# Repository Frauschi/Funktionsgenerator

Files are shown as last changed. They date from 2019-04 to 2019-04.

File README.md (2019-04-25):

# Funktionsgenerator

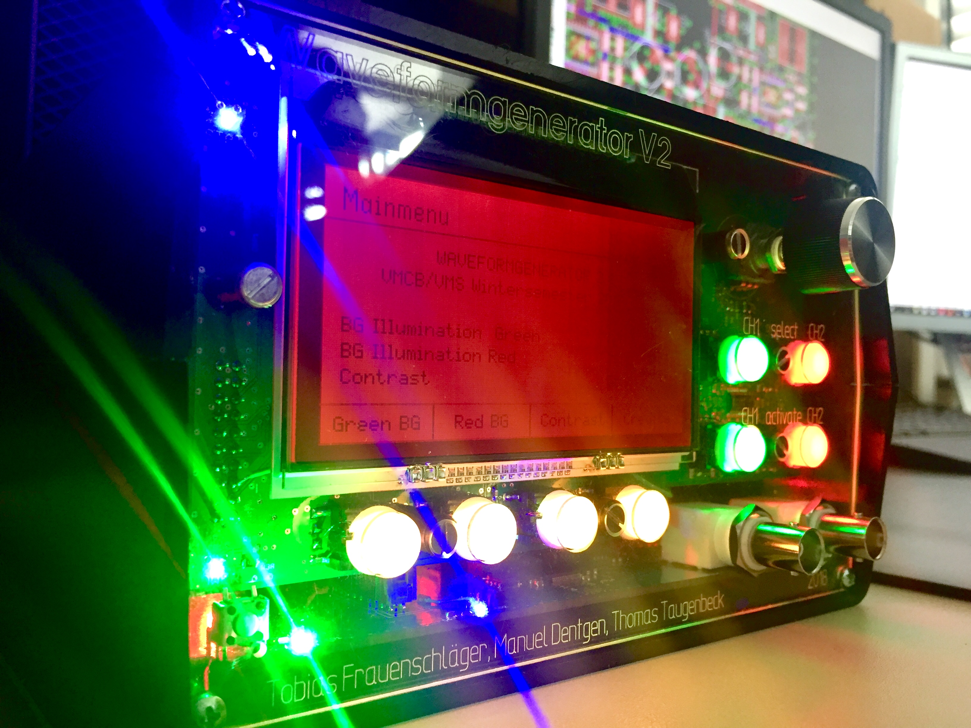
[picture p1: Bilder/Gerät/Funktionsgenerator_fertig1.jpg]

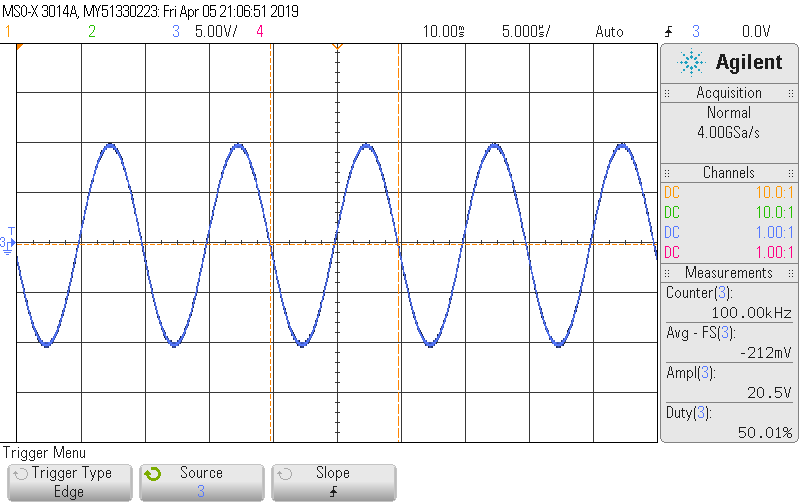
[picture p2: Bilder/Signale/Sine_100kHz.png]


Dieses Repository beinhaltet alle relevaten Dateien für den Bau eines Funktionsgenerators. Dieser ist
im Rahmen einer Projektarbeit and der *Ostbayerischen Technischen Hochschule Regensburg* enstanden.

### Specs des Funktionsgenerators

- Zwei unabhängige Ausgangskanäle
- Signalformen: Sinus, Recheck (einstellbarer Duty-Cycle), Dreieck, Sägezahn (ansteigend und abfallend)
- Frequenz: 1Hz – 10MHz
- Ausgangsspannung: -10V – +10V 
- Signal-Offset: -5V – +5V
- Signal-Phase -180° – +180°

### Entwickler

- Manuel Dentgen
- Tobias Frauenschläger
- Thomas Taugenbeck

### Verzeichnisstruktur

- `Bilder` 
	
	Dieses Verzeichnis beinhaltet sowohl Bilder vom Gerät selbst (3D Modell und tatsächliches Gerät) als 
	auch Bilder von den erzeugten Signalen.
	
- `Dokumentation` 

	Dieser Ordner enthält zum einen die Projektdokumentation und zum anderen eine Bedienungsanleitung für den 
	fertigen Funktionsgenerator.
	
- `Hardware` 

	Hier sind alle Dateien für die drei entwickelten Platinen abgelegt (Schaltplan und Layout).
	
- `Software` 
	
	In diesem Verzeichnis ist die Firmware für den Mikrocontroller zu finden, der das ganze Gerät steuert.

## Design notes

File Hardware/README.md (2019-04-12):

# Hardware Funktionsgenerator

In diesem Verzeichnis ist die selbstentwickelte Hardware für den Funktionsgenerator zu finden, 
aufgeteilt auf die drei Platinen `Frontpanel`, `Hauptplatine` und `Netzteilplatine`. Im jeweiligen Ordner 
sind die Schaltplan- und Layout-Dateien abgelegt, wobei diese mit dem Programm 
[Eagle](https://www.autodesk.com/products/eagle/overview) in Version 7.7 erstellt wurden. Die Schaltpläne
sind zudem als PDF verfügbar.

## Dokumentation

Die Dokumentation der Hardware ist in der Projektdokumentation im Verzeichnis `Dokumentation` zu finden.

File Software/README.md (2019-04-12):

# Software Funktionsgenerator

In diesem Verzeichnis ist die Firmware für den Funktionsgenerator zu finden. Es handelt sich 
um ein Projekt für die IDE [Eclipse](https://www.eclipse.org/ide/) mit dem Zusatzplugin 
[System Workbench for STM32](http://www.openstm32.org/System%2BWorkbench%2Bfor%2BSTM32). 

## Dokumentation

Für die Dokumentation des Codes bitte in der Projektdokumentation im Verzeichnis `Dokumentation` nachlesen.

## How to build

Nach dem Import in Eclipse sind zwei Konfigurationen vorhanden: `Debug` und `Release`. 

Ein `Debug` Build ermöglicht das Debuggen mittels GDB, wobei keinerlei Code-Optimierungen erfolgen.

Ein Build in der `Release` Konfiguration optimiert den Code mit `-Os`. Damit wird der Code um einiges
schneller und die Binary-Size deutlich kleiner, es kann jedoch nicht mehr gedebugged werden.

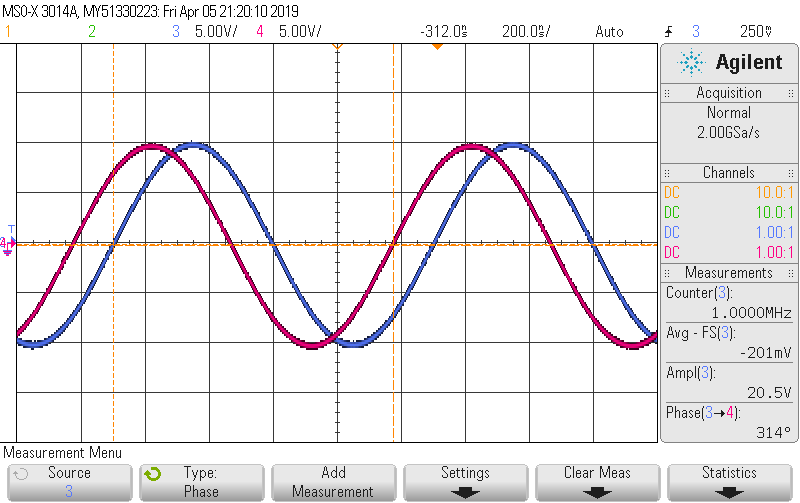
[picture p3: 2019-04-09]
Bilder/Signale/Sine_1MHz_-45deg.png

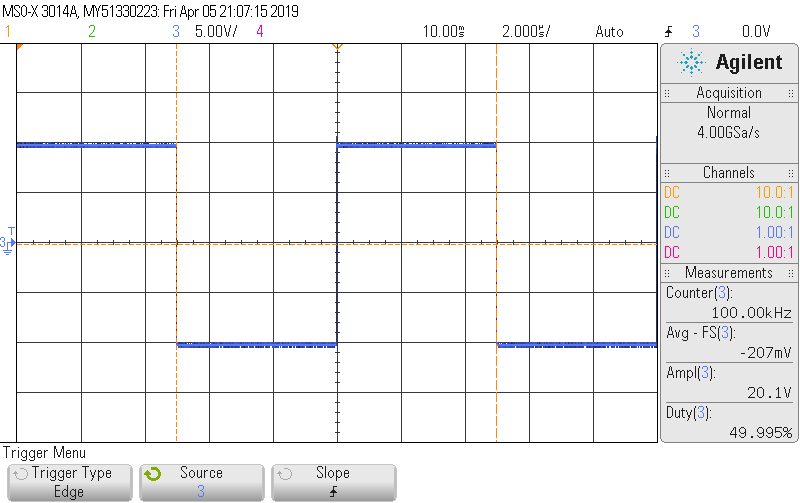
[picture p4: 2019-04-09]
Bilder/Signale/Rect_100kHz.png

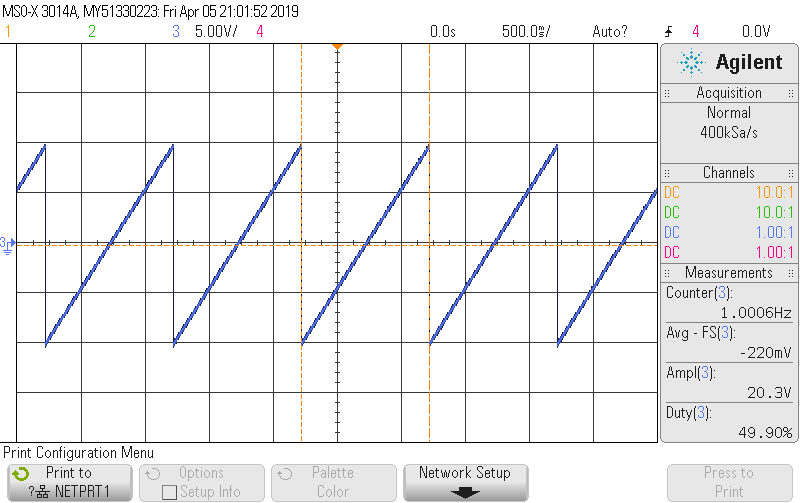
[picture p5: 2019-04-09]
Bilder/Signale/Saw_pos_1Hz.png

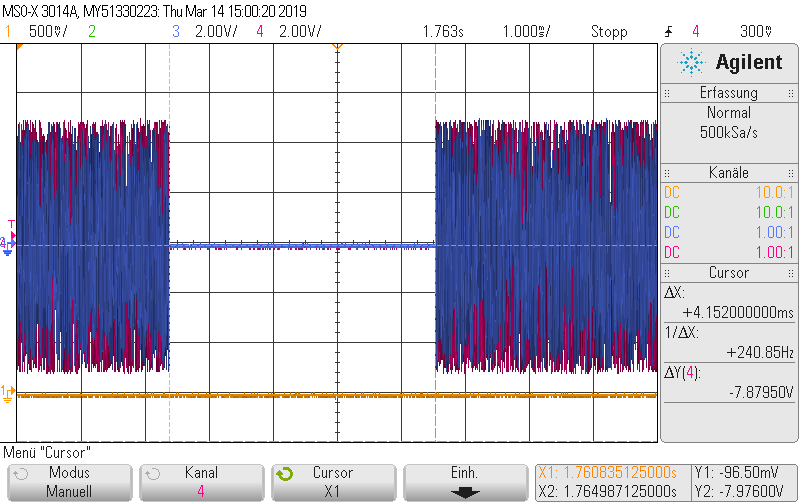
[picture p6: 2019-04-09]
Bilder/Signale/Signalunterbrechung_bei_Parameterumschaltung.png

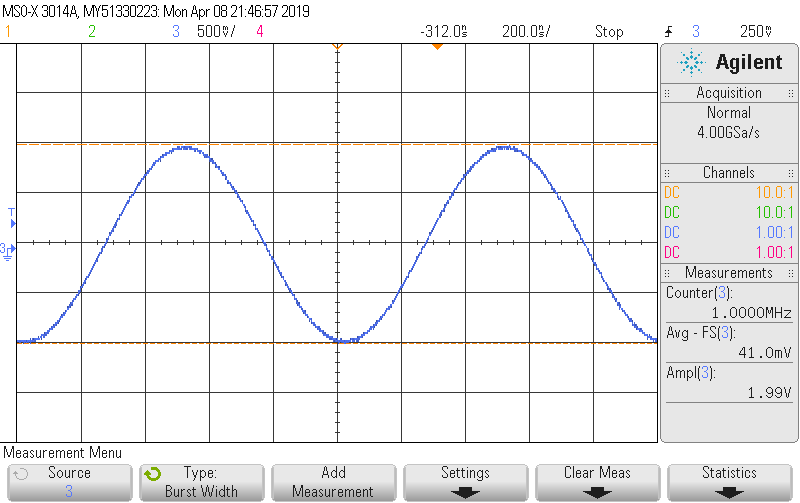
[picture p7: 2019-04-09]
Bilder/Signale/Sine_1MHz_2Vpp.png

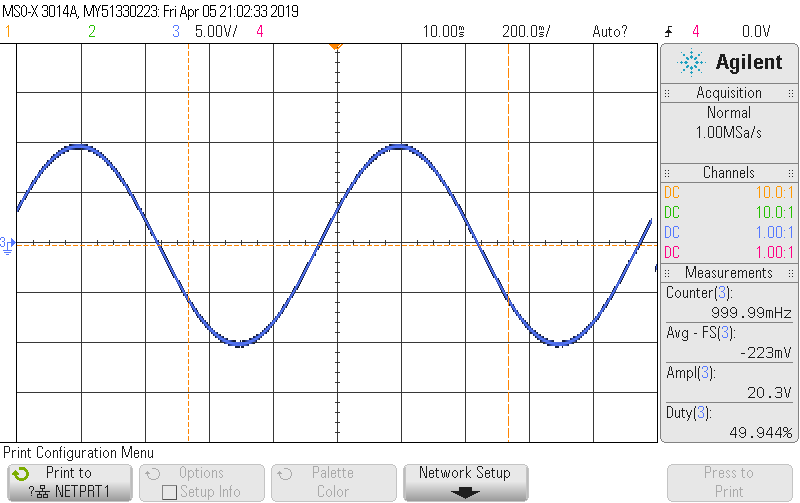
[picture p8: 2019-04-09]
Bilder/Signale/Sine_1Hz.png

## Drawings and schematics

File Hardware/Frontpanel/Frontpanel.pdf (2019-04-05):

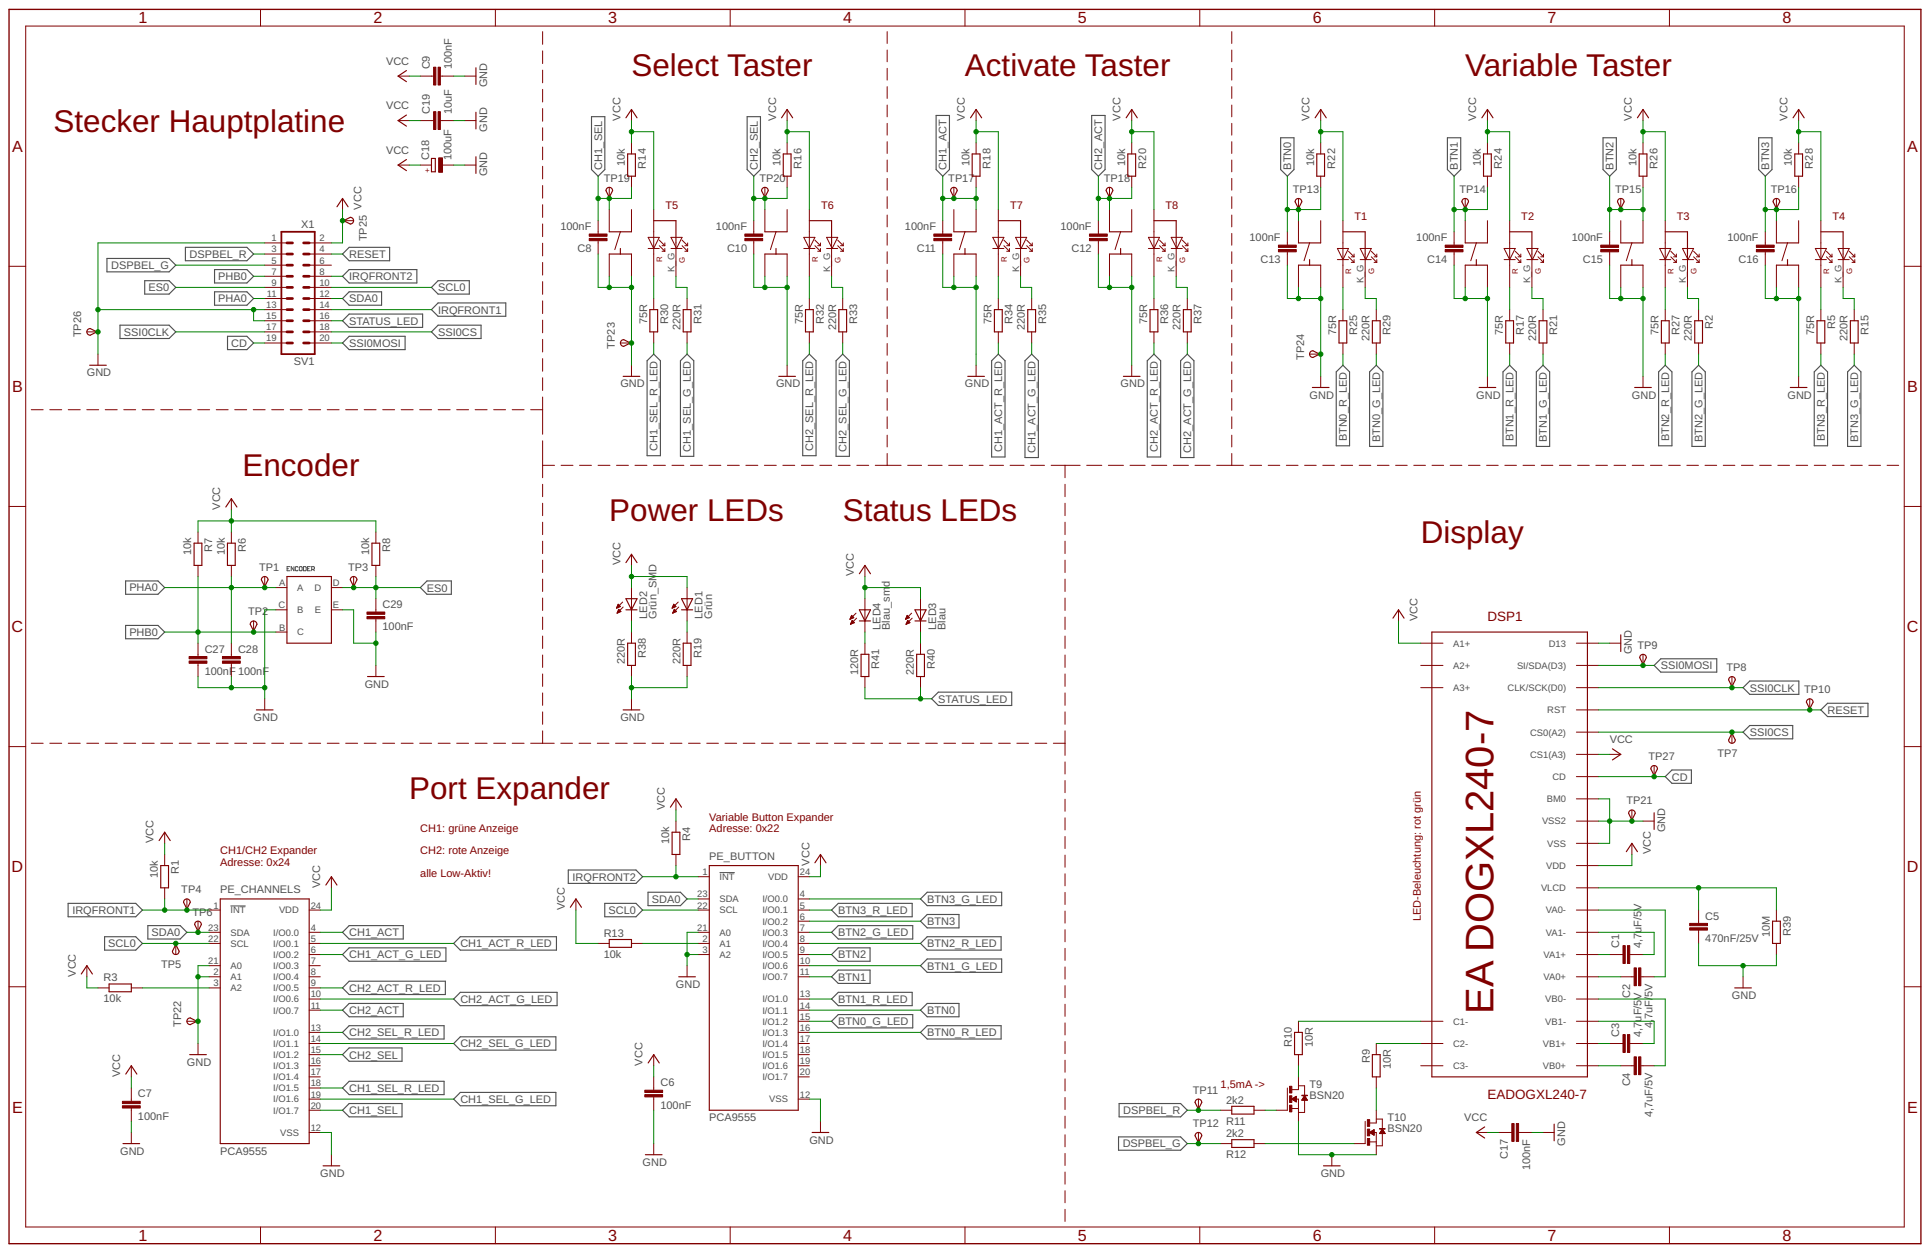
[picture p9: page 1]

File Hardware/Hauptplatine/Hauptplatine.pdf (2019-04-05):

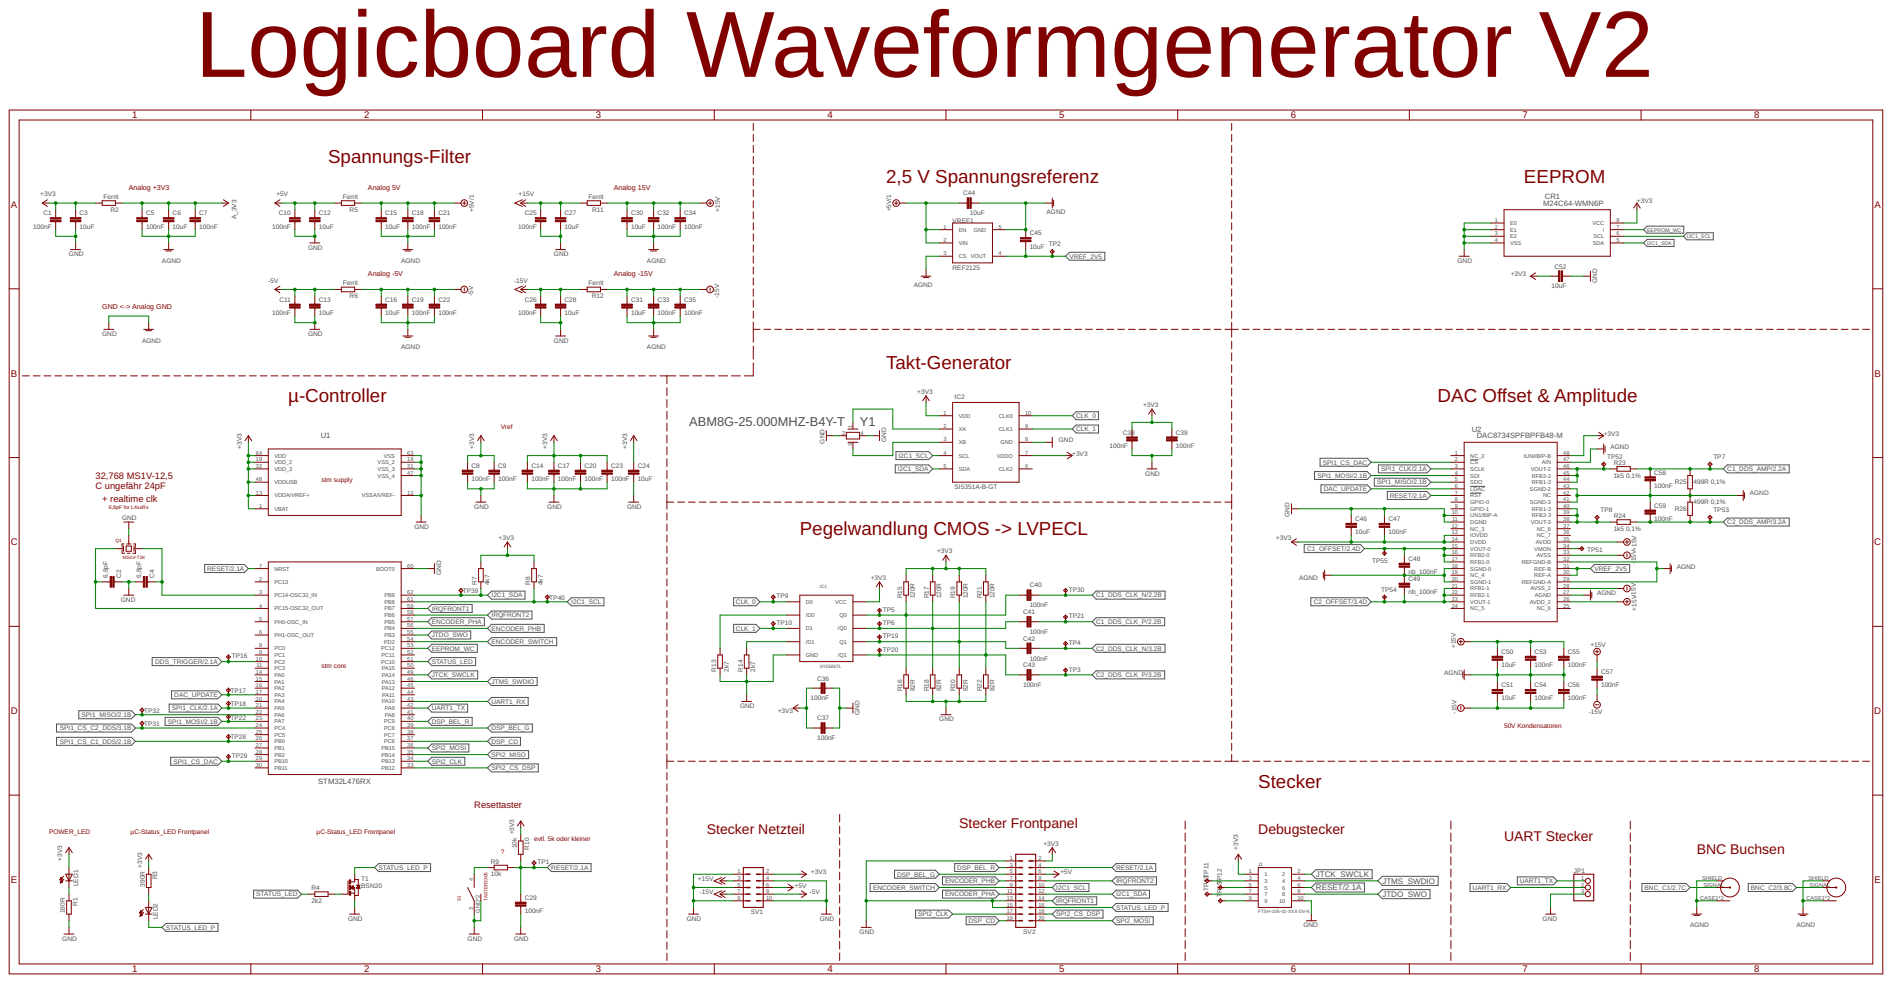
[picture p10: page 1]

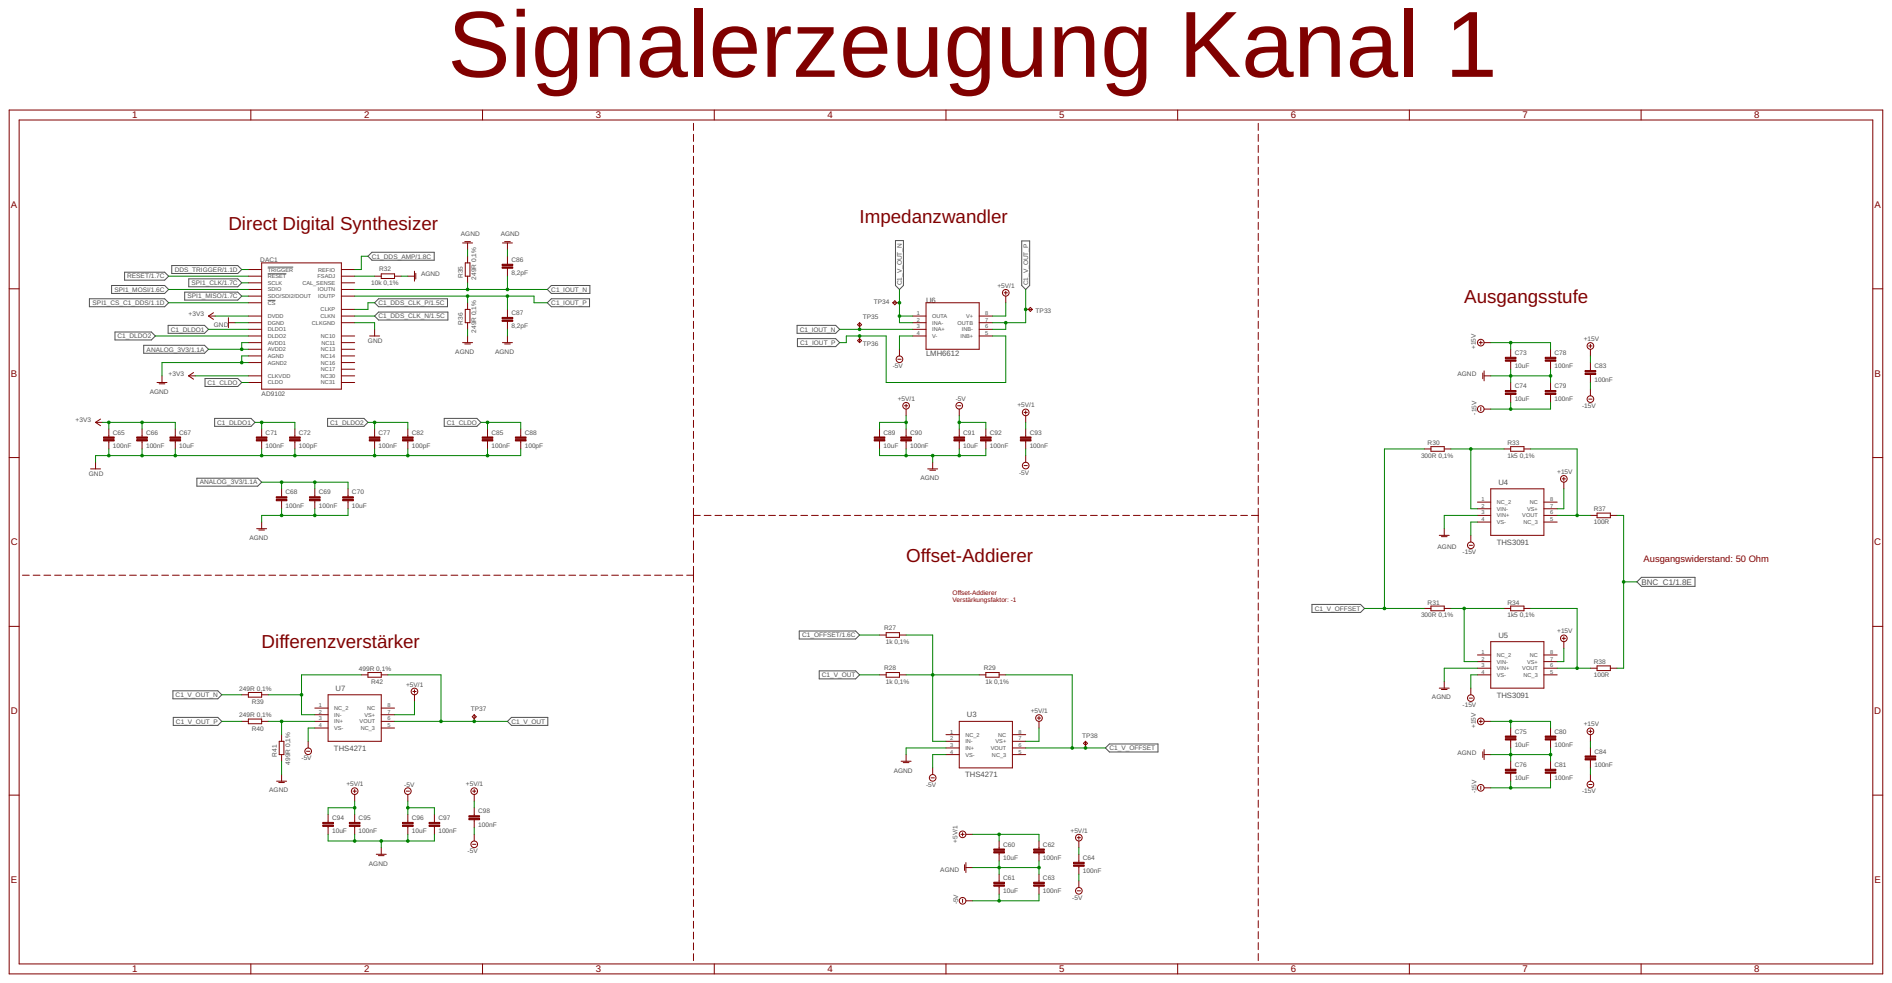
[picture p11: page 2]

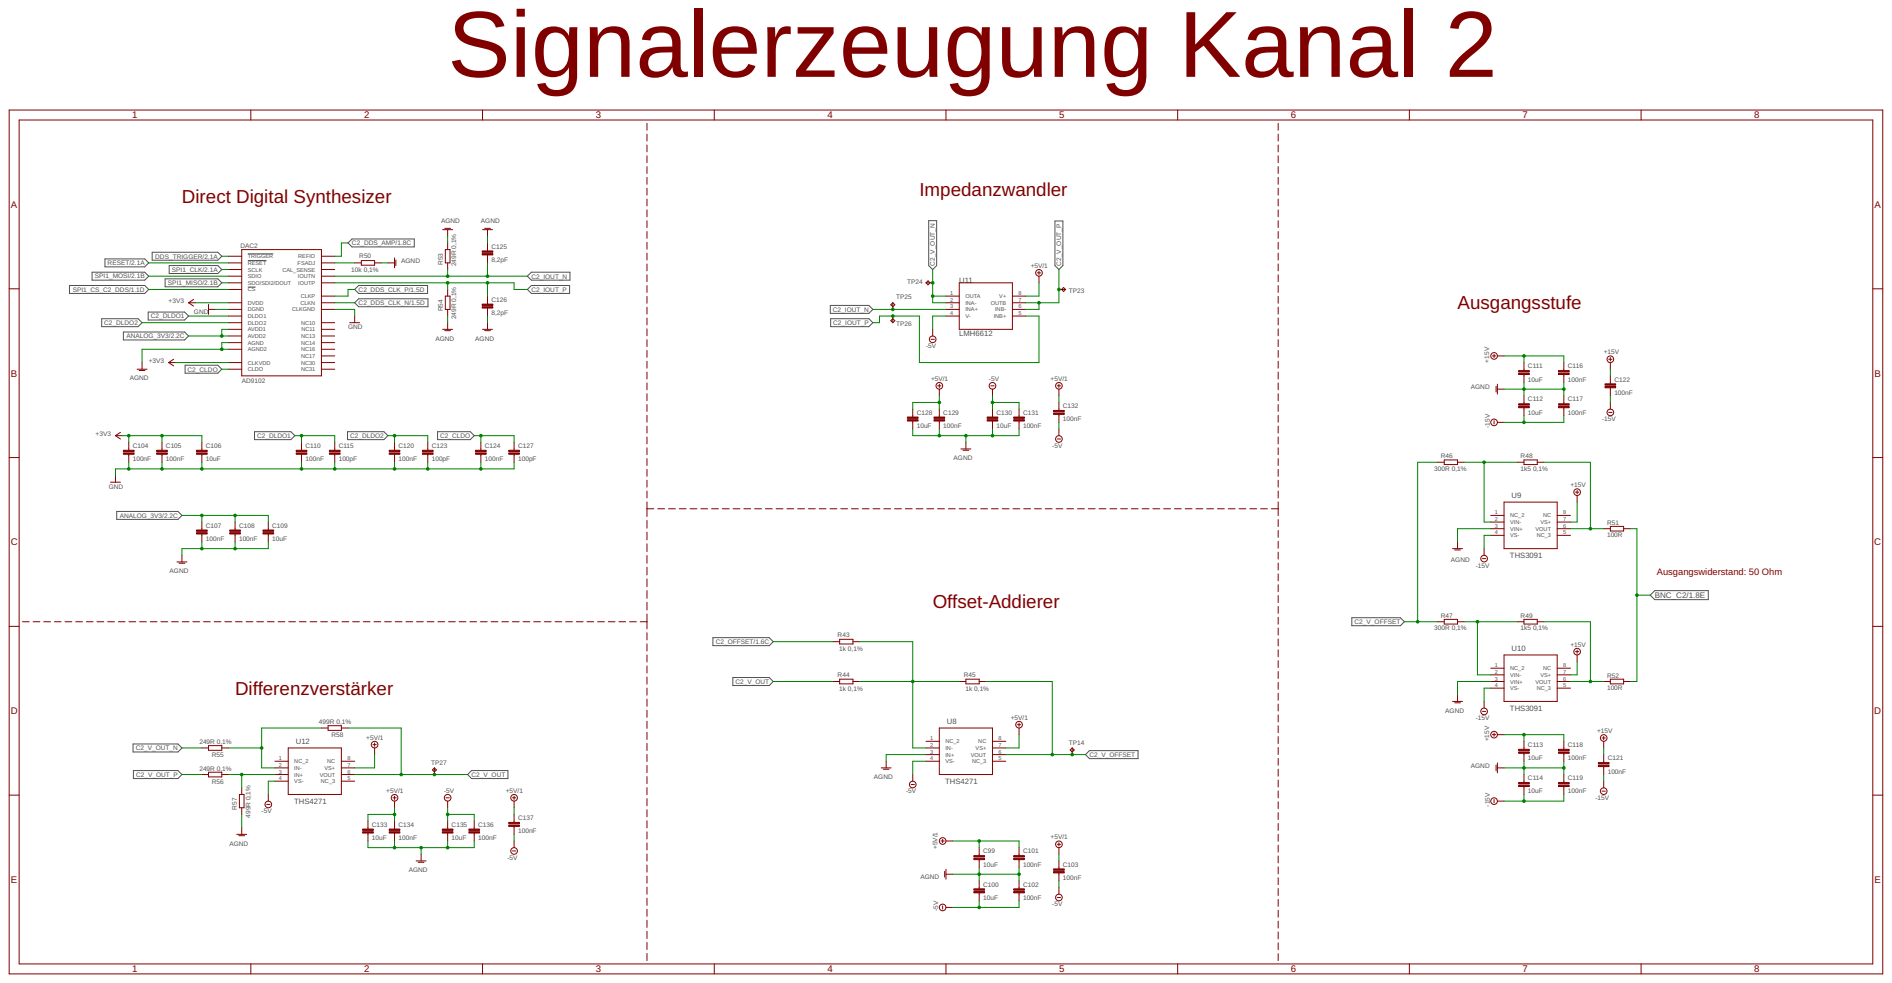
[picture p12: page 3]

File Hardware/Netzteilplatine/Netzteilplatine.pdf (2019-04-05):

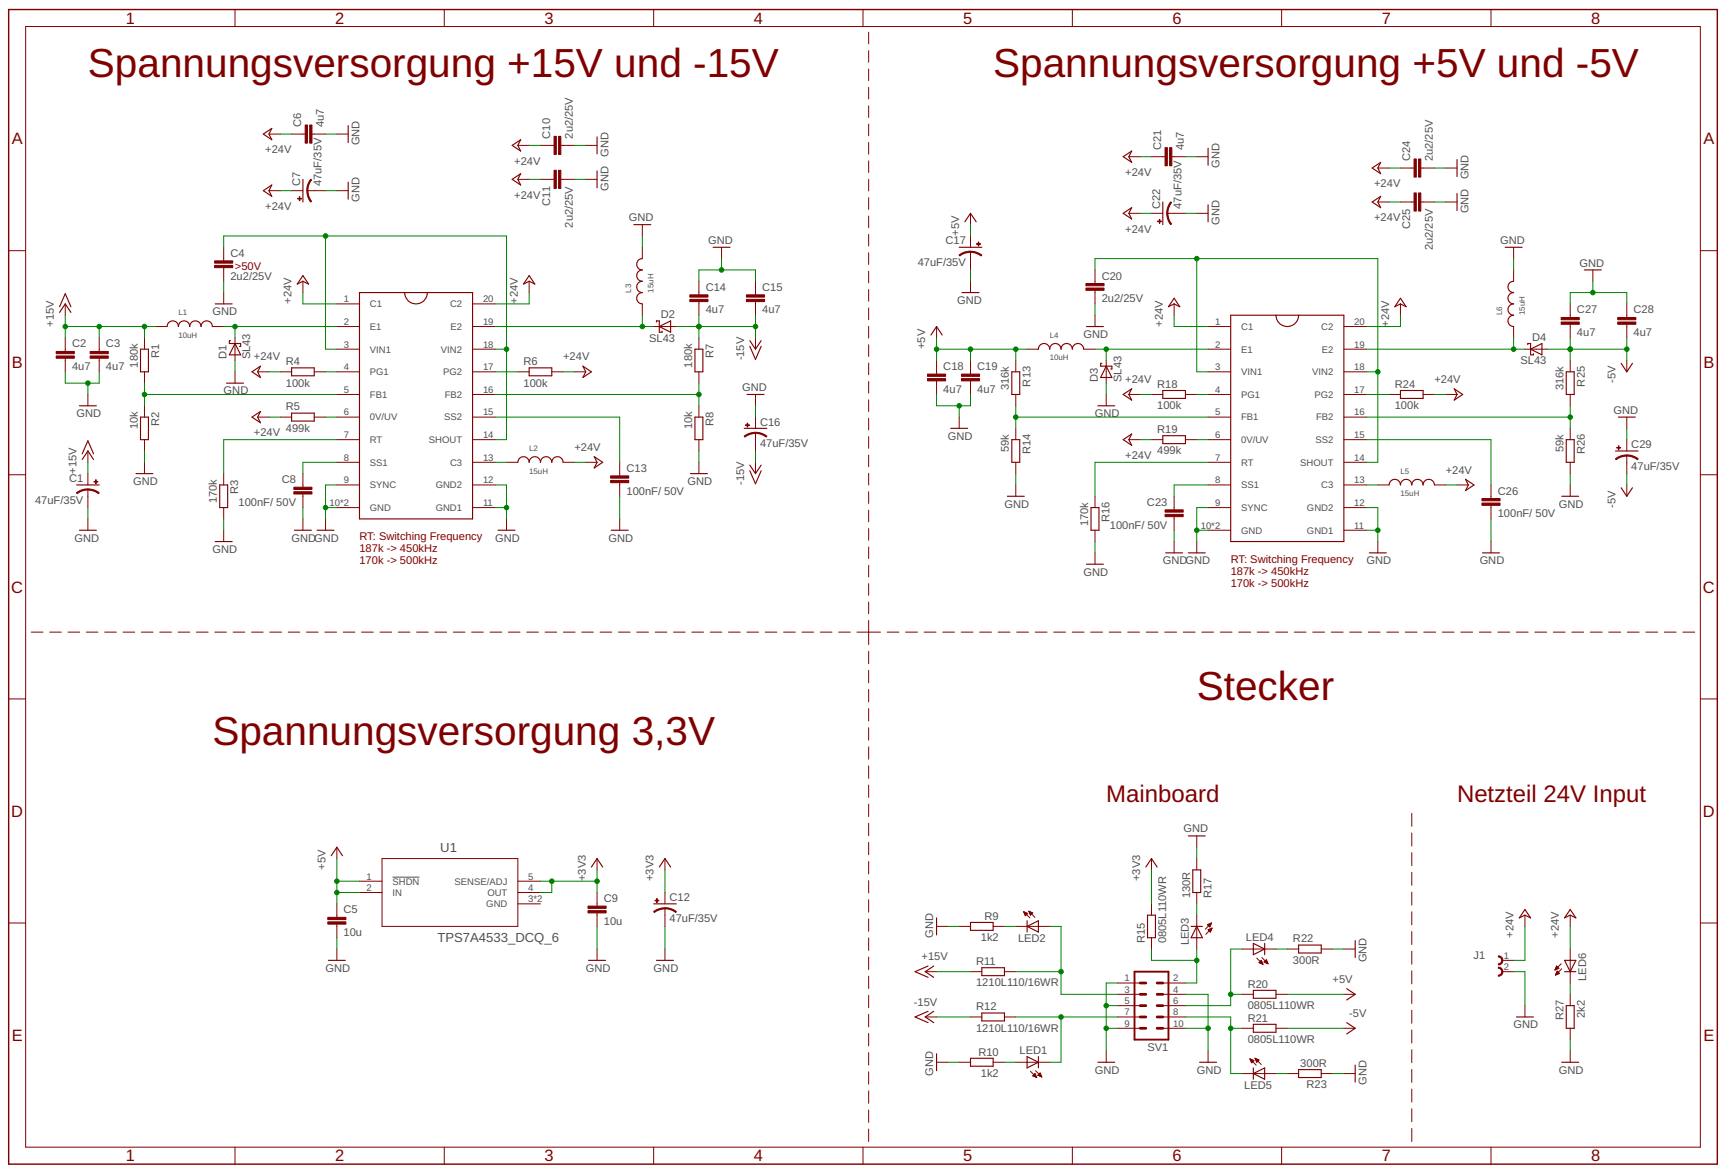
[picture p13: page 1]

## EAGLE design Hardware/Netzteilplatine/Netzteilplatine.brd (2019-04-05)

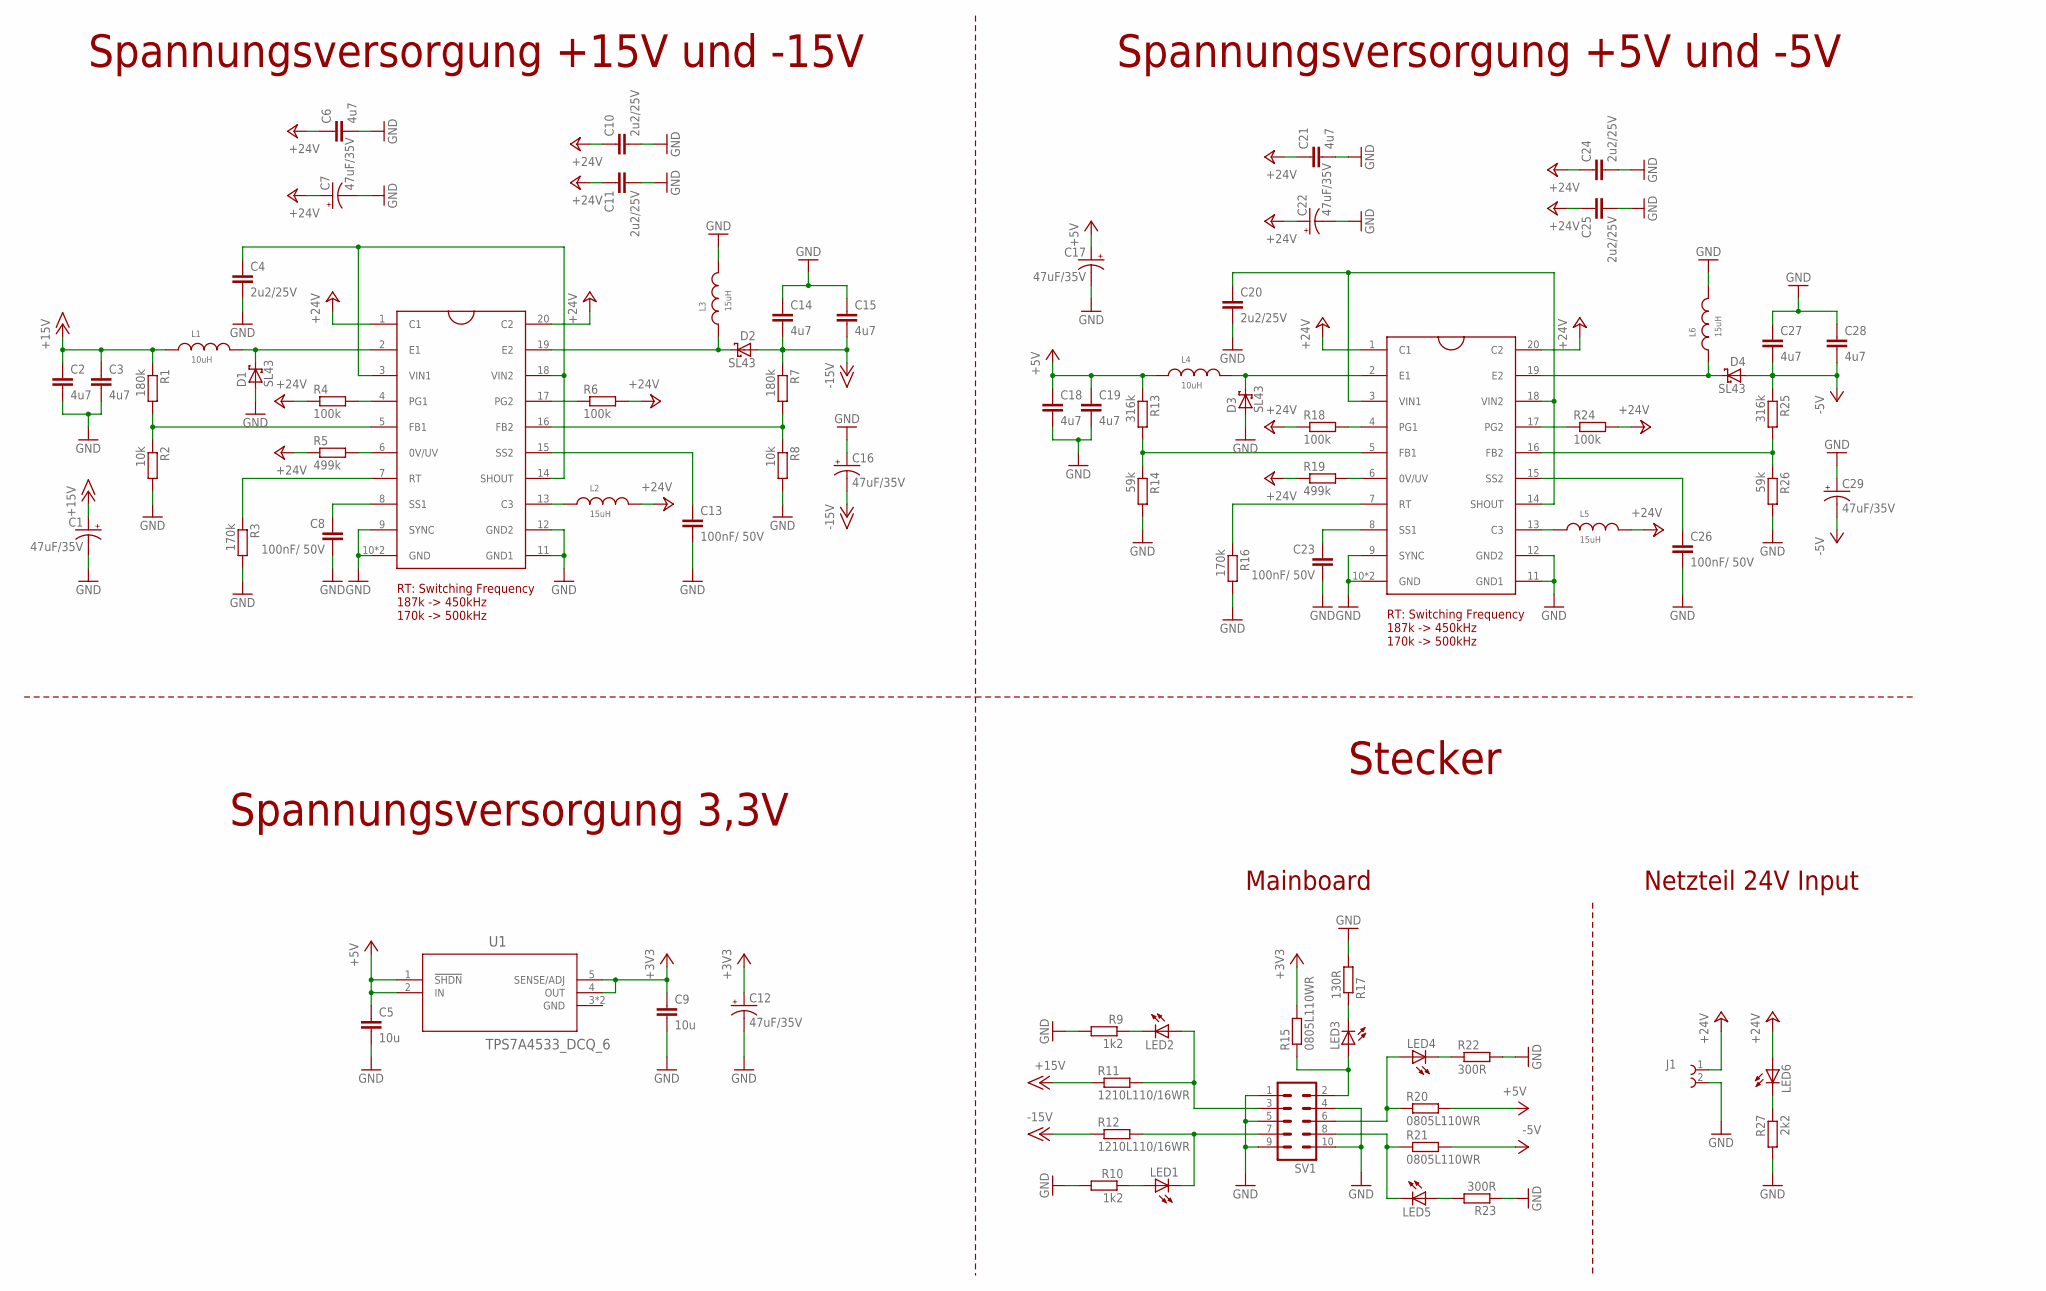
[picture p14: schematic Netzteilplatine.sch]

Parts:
C1, C7, C12, C16, C17, C22, C29: 47uF/35V; PANASONIC_D
C2, C3, C6, C14, C15, C18, C19, C21, C27, C28: 4u7; C1210
C4, C10, C11, C20, C24, C25: 2u2/25V; C1210
C5, C9: 10u; C0805
C8, C13, C23, C26: 100nF/ 50V; C0603
D1, D2, D3, D4: SL43; SMC
J1: 691137810002
L1, L4: 10uH; WE-PD_7332-7345_PLASTIC_BASE
L2, L3, L5, L6: 15uH; WE-PD2SR_7850
LED1, LED2, LED3, LED4, LED5, LED6: LEDCHIPLED_0603; CHIPLED_0603
R1, R7: 180k; R0603
R2, R8: 10k; R0603
R3, R16: 170k; R0603
R4, R6, R18, R24: 100k; R0603
R5, R19: 499k; R0603
R9, R10: 1k2; R0603
R11, R12: 1210L110/16WR; R1206
R13, R25: 316k; R0603
R14, R26: 59k; R0603
R15, R20, R21: 0805L110WR; R0805
R17: 130R; R0603
R22, R23: 300R; R0603
R27: 2k2; R0603
SV1: ML10
U1: TPS7A4533_DCQ_6; DCQ6
U2, U3: LT8471; TSSOP20

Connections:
+3V3: C9.1, C12.+, R15.2, U1.4 (OUT), U1.5 (SENSE/ADJ)
+5V: C5.1, C17.+, C18.1, C19.1, L4.1, R13.1, R20.2, U1.1 (!SHDN), U1.2 (IN)
+15V: C1.+, C2.1, C3.1, L1.1, R1.1, R11.1
+24V: C6.1, C7.+, C10.1, C11.1, C21.1, C22.+, C24.1, C25.1, J1.1, L2.2, L5.2, LED6.A, R4.1, R5.1, R6.2, R18.1, R19.1, R24.2, U2.1 (C1), U2.20 (C2), U3.1 (C1), U3.20 (C2)
-5V: C27.2, C28.2, C29.-, D4.A, R21.2, R25.1
-15V: C14.2, C15.2, C16.-, D2.A, R7.1, R12.1
GND: C1.-, C2.2, C3.2, C4.2, C5.2, C6.2, C7.-, C8.2, C9.2, C10.2, C11.2, C12.-, C13.2, C14.1, C15.1, C16.+, C17.-, C18.2, C19.2, C20.2, C21.2, C22.-, C23.2, C24.2, C25.2, C26.2, C27.1, C28.1, C29.+, D1.A, D3.A, J1.2, L3.2, L6.2, R2.2, R3.2, R8.2, R9.2, R10.2, R14.2, R16.2, R17.2, R22.2, R23.1, R26.2, R27.2, SV1.1, SV1.4, SV1.5, SV1.9, SV1.10, U1.3 (GND), U1.P$1 (GND), U2.9 (SYNC), U2.10 (GND), U2.11 (GND1), U2.12 (GND2), U2.P$1 (GND), U3.9 (SYNC), U3.10 (GND), U3.11 (GND1), U3.12 (GND2), U3.P$1 (GND)
unnamed: C4.1, U2.3 (VIN1), U2.14 (SHOUT), U2.18 (VIN2)
unnamed: R7.2, R8.1, U2.16 (FB2)
unnamed: R1.2, R2.1, U2.5 (FB1)
unnamed: R5.2, U2.6 (0V/UV)
unnamed: C20.1, U3.3 (VIN1), U3.14 (SHOUT), U3.18 (VIN2)
unnamed: C8.1, U2.8 (SS1)
unnamed: R19.2, U3.6 (0V/UV)
unnamed: C13.1, U2.15 (SS2)
unnamed: C23.1, U3.8 (SS1)
unnamed: C26.1, U3.15 (SS2)
unnamed: R25.2, R26.1, U3.16 (FB2)
unnamed: R13.2, R14.1, U3.5 (FB1)
unnamed: R3.1, U2.7 (RT)
unnamed: R16.1, U3.7 (RT)
unnamed: D1.C, L1.2, U2.2 (E1)
unnamed: D2.C, L3.1, U2.19 (E2)
unnamed: L2.1, U2.13 (C3)
unnamed: D3.C, L4.2, U3.2 (E1)
unnamed: R6.1, U2.17 (PG2)
unnamed: R4.2, U2.4 (PG1)
unnamed: D4.C, L6.1, U3.19 (E2)
unnamed: L5.1, U3.13 (C3)
unnamed: R24.1, U3.17 (PG2)
unnamed: R18.2, U3.4 (PG1)
unnamed: LED3.A, R15.1, SV1.2
unnamed: LED4.A, R20.1, SV1.6
unnamed: LED4.C, R22.1
unnamed: LED1.C, R12.2, SV1.7
unnamed: LED5.C, R21.1, SV1.8
unnamed: LED5.A, R23.2
unnamed: LED2.A, R11.2, SV1.3
unnamed: LED3.C, R17.1
unnamed: LED2.C, R9.1
unnamed: LED1.A, R10.1
unnamed: LED6.C, R27.1

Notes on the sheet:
Spannungsversorgung +15V und -15V
Spannungsversorgung 3,3V
RT: Switching Frequency 187k -> 450kHz 170k -> 500kHz
Spannungsversorgung +5V und -5V
Stecker
Mainboard
Netzteil 24V Input

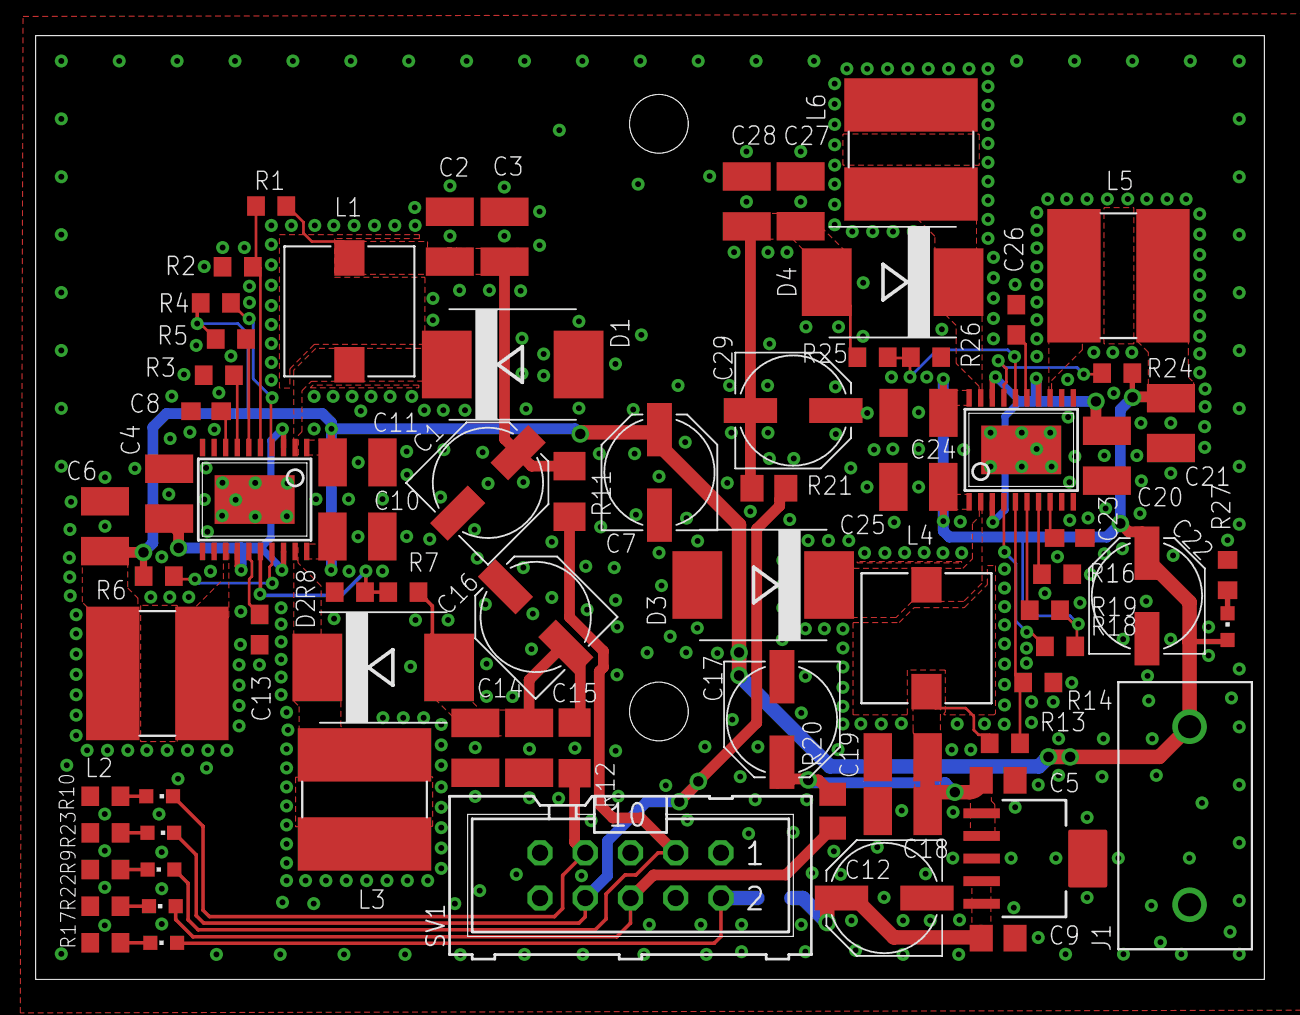
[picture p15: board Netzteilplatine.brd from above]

Board: 2 copper layers, 69.0 x 53.0 mm, 77 parts (1 on the bottom side), 42 nets.

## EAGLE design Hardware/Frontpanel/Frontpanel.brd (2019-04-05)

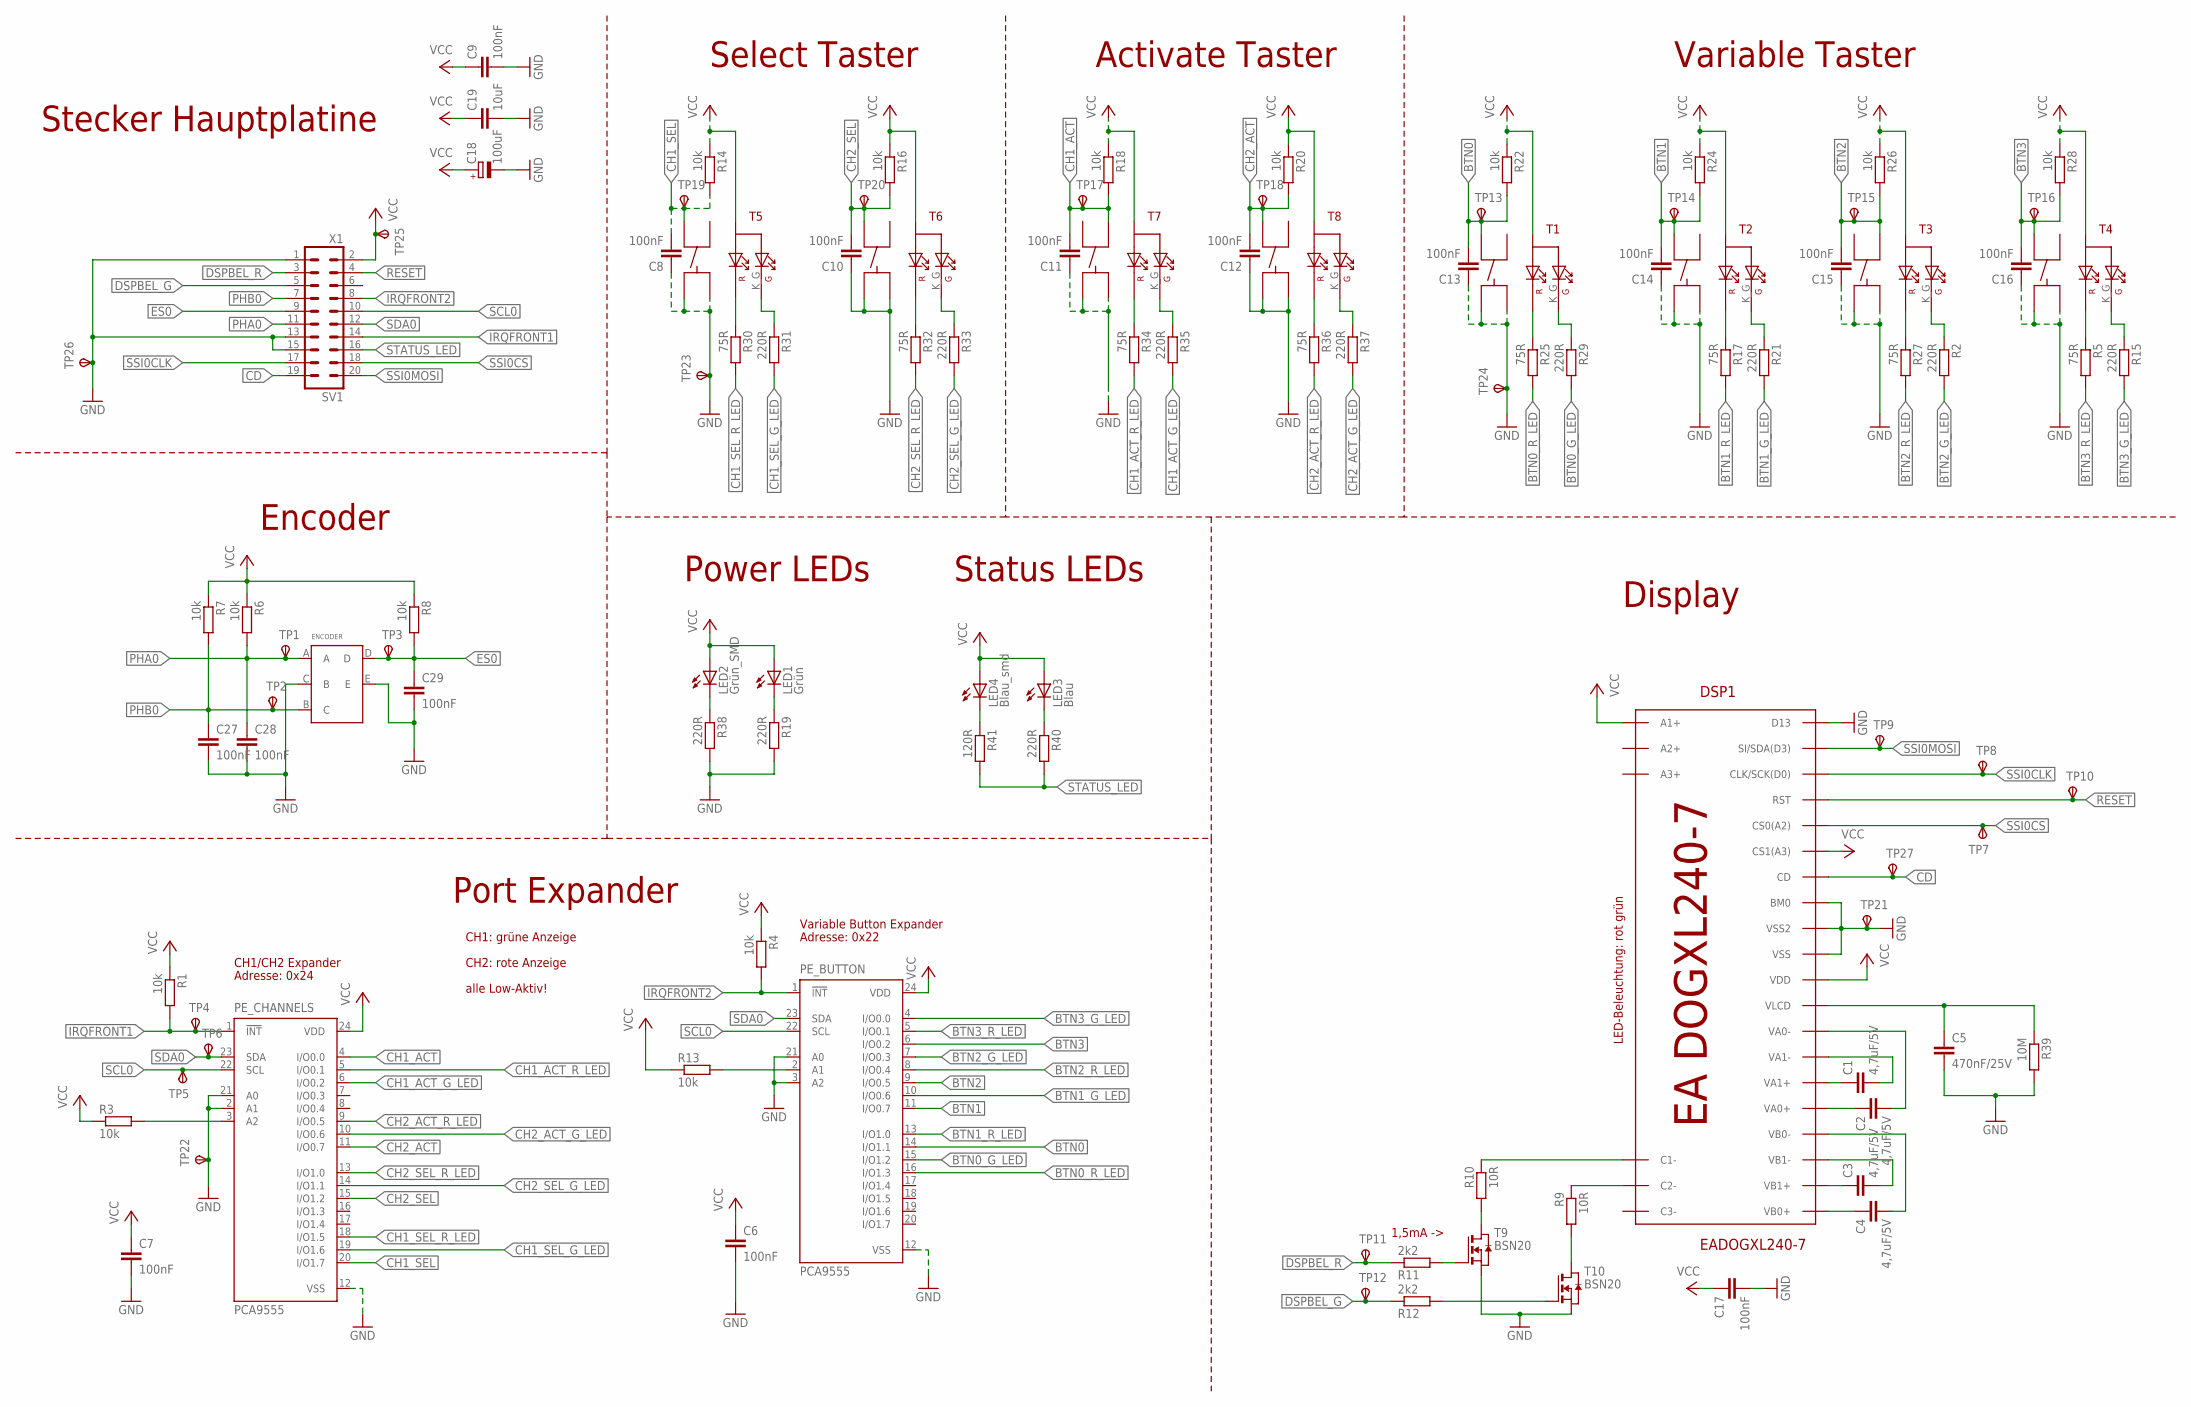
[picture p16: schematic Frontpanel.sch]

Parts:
C1, C2, C3, C4: 4,7uF/5V; C0805
C5: 470nF/25V; C0603
C6, C7, C8, C9, C10, C11, C12, C13, C14, C15, C16, C17, C27, C28, C29: 100nF; C0603
C18: 100uF; CT7343
C19: 10uF; C0805
DSP1: EADOGXL240-7
ENCODER: ENCODER
LED1: Grün; LED5MM
LED2: Grün_SMD; CHIP-LED0603
LED3: Blau; LED5MM
LED4: Blau_smd; CHIP-LED0603
PE_BUTTON: PCA9555; SSOP24_DBQ
PE_CHANNELS: PCA9555; SSOP24_DBQ
R1, R3, R4, R6, R7, R8, R13, R14, R16, R18, R20, R22, R24, R26, R28: 10k; R0603
R2, R15, R19, R21, R29, R31, R33, R35, R37, R38, R40: 220R; R0603
R5, R17, R25, R27, R30, R32, R34, R36: 75R; R0603
R9, R10: 10R; M1206
R11, R12: 2k2; R0603
R39: 10M; R0603
R41: 120R; R0603
SV1: X1; ML20
T1, T2, T3, T4, T5, T6, T7, T8: TASTER_2FSH9_E_BEL; TASTER_3FSH9_SMD_E
T9, T10: BSN20; SOT-23
TP1, TP2, TP3, TP4, TP5, TP6, TP7, TP8, TP9, TP10, TP11, TP12, TP13, TP14, TP15, TP16, TP17, TP18, TP19, TP20, TP21, TP22, TP23, TP24, TP25, TP26, TP27: TPSB1,27; B1,27

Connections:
BTN0: C13.2, PE_BUTTON.14 (I/O1.1), R22.2, T1.13, TP13.TP
BTN0_G_LED: PE_BUTTON.15 (I/O1.2), R29.2
BTN0_R_LED: PE_BUTTON.16 (I/O1.3), R25.2
BTN1: C14.2, PE_BUTTON.11 (I/O0.7), R24.2, T2.13, TP14.TP
BTN1_G_LED: PE_BUTTON.10 (I/O0.6), R21.2
BTN1_R_LED: PE_BUTTON.13 (I/O1.0), R17.2
BTN2: C15.2, PE_BUTTON.9 (I/O0.5), R26.2, T3.23, TP15.TP
BTN2_G_LED: PE_BUTTON.7 (I/O0.3), R2.2
BTN2_R_LED: PE_BUTTON.8 (I/O0.4), R27.2
BTN3: C16.2, PE_BUTTON.6 (I/O0.2), R28.2, T4.13, TP16.TP
BTN3_G_LED: PE_BUTTON.4 (I/O0.0), R15.2
BTN3_R_LED: PE_BUTTON.5 (I/O0.1), R5.2
CD: DSP1.CD, SV1.19, TP27.TP
CH1_ACT: C11.2, PE_CHANNELS.4 (I/O0.0), R18.2, T7.23, TP17.TP
CH1_ACT_G_LED: PE_CHANNELS.6 (I/O0.2), R35.2
CH1_ACT_R_LED: PE_CHANNELS.5 (I/O0.1), R34.2
CH1_SEL: C8.2, PE_CHANNELS.20 (I/O1.7), R14.2, T5.13, TP19.TP
CH1_SEL_G_LED: PE_CHANNELS.19 (I/O1.6), R31.2
CH1_SEL_R_LED: PE_CHANNELS.18 (I/O1.5), R30.2
CH2_ACT: C12.2, PE_CHANNELS.11 (I/O0.7), R20.2, T8.13, TP18.TP
CH2_ACT_G_LED: PE_CHANNELS.10 (I/O0.6), R37.2
CH2_ACT_R_LED: PE_CHANNELS.9 (I/O0.5), R36.2
CH2_SEL: C10.2, PE_CHANNELS.15 (I/O1.2), R16.2, T6.13, TP20.TP
CH2_SEL_G_LED: PE_CHANNELS.14 (I/O1.1), R33.2
CH2_SEL_R_LED: PE_CHANNELS.13 (I/O1.0), R32.2
DSPBEL_G: R12.1, SV1.5, TP12.TP
DSPBEL_R: R11.1, SV1.3, TP11.TP
ES0: C29.1, ENCODER.D, R8.2, SV1.9, TP3.TP
GND: C5.2, C6.2, C7.2, C8.1, C9.2, C10.1, C11.1, C12.1, C13.1, C14.1, C15.1, C16.1, C17.2, C18.-, C19.2, C27.2, C28.2, C29.2, DSP1.BM0, DSP1.D13, DSP1.VSS1 (VSS), DSP1.VSS2, ENCODER.C (B), ENCODER.E, PE_BUTTON.3 (A2), PE_BUTTON.12 (VSS), PE_BUTTON.21 (A0), PE_CHANNELS.2 (A1), PE_CHANNELS.12 (VSS), PE_CHANNELS.21 (A0), R19.2, R38.2, R39.2, SV1.1, SV1.13, SV1.15, T1.14, T1.24, T2.14, T2.24, T3.14, T3.24, T4.14, T4.24, T5.14, T5.24, T6.14, T6.24, T7.14, T7.24, T8.14, T8.24, T9.2 (S), T10.2 (S), TP21.TP, TP22.TP, TP23.TP, TP24.TP, TP26.TP
IRQFRONT1: PE_CHANNELS.1 (!INT), R1.2, SV1.14, TP4.TP
IRQFRONT2: PE_BUTTON.1 (!INT), R4.2, SV1.8
unnamed: PE_CHANNELS.3 (A2), R3.2
unnamed: R27.1, T3.K_R (KR)
unnamed: DSP1.C1-, R10.1
unnamed: PE_BUTTON.2 (A1), R13.2
unnamed: R11.2, T9.3 (G)
unnamed: DSP1.C2-, R9.1
unnamed: R12.2, T10.3 (G)
unnamed: R29.1, T1.K_G (KG)
unnamed: R25.1, T1.K_R (KR)
unnamed: R17.1, T2.K_R (KR)
unnamed: C1.1, DSP1.VA1+
unnamed: C2.1, DSP1.VA0+
unnamed: C3.1, DSP1.VB1+
unnamed: C4.1, DSP1.VB0+
unnamed: C3.2, DSP1.VB1-
unnamed: C4.2, DSP1.VB0-
unnamed: R9.2, T10.1 (D)
unnamed: R10.2, T9.1 (D)
unnamed: R21.1, T2.K_G (KG)
unnamed: R36.1, T8.K_R (KR)
unnamed: R2.1, T3.K_G (KG)
unnamed: R5.1, T4.K_R (KR)
unnamed: R15.1, T4.K_G (KG)
unnamed: R37.1, T8.K_G (KG)
unnamed: R34.1, T7.K_R (KR)
unnamed: R35.1, T7.K_G (KG)
unnamed: R32.1, T6.K_R (KR)
unnamed: R33.1, T6.K_G (KG)
unnamed: R30.1, T5.K_R (KR)
unnamed: R31.1, T5.K_G (KG)
unnamed: C1.2, DSP1.VA1-
unnamed: LED1.K (C), R19.1
unnamed: LED2.C, R38.1
unnamed: C2.2, DSP1.VA0-
unnamed: LED3.K (C), R40.1
unnamed: C5.1, DSP1.VLCD, R39.1
unnamed: LED4.C, R41.1
PHA0: C28.1, ENCODER.A, R6.2, SV1.11, TP1.TP
PHB0: C27.1, ENCODER.B (C), R7.2, SV1.7, TP2.TP
RESET: DSP1.RST, SV1.4, TP10.TP
SCL0: PE_BUTTON.22 (SCL), PE_CHANNELS.22 (SCL), SV1.10, TP5.TP
SDA0: PE_BUTTON.23 (SDA), PE_CHANNELS.23 (SDA), SV1.12, TP6.TP
SSI0CLK: DSP1.SCK(D0) (CLK/SCK(D0)), SV1.17, TP8.TP
SSI0CS: DSP1.CS0(A2), SV1.18, TP7.TP
SSI0MOSI: DSP1.SDA(D3) (SI/SDA(D3)), SV1.20, TP9.TP
STATUS_LED: R40.2, R41.2, SV1.16
VCC: C6.1, C7.1, C9.1, C17.1, C18.+, C19.1, DSP1.A1+, DSP1.CS1(A3), DSP1.VDD, LED1.A, LED2.A, LED3.A, LED4.A, PE_BUTTON.24 (VDD), PE_CHANNELS.24 (VDD), R1.1, R3.1, R4.1, R6.1, R7.1, R8.1, R13.1, R14.1, R16.1, R18.1, R20.1, R22.1, R24.1, R26.1, R28.1, SV1.2, T1.A, T2.A, T3.A, T4.A, T5.A, T6.A, T7.A, T8.A, TP25.TP

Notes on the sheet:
Stecker Hauptplatine
Adresse: 0x24
Encoder
Port Expander
Adresse: 0x22
CH1: grüne Anzeige
CH2: rote Anzeige
Variable Button Expander
CH1/CH2 Expander
alle Low-Aktiv!
Select Taster
Activate Taster
Variable Taster
Power LEDs
LED-Beleuchtung: rot grün
1,5mA ->
Status LEDs
Display

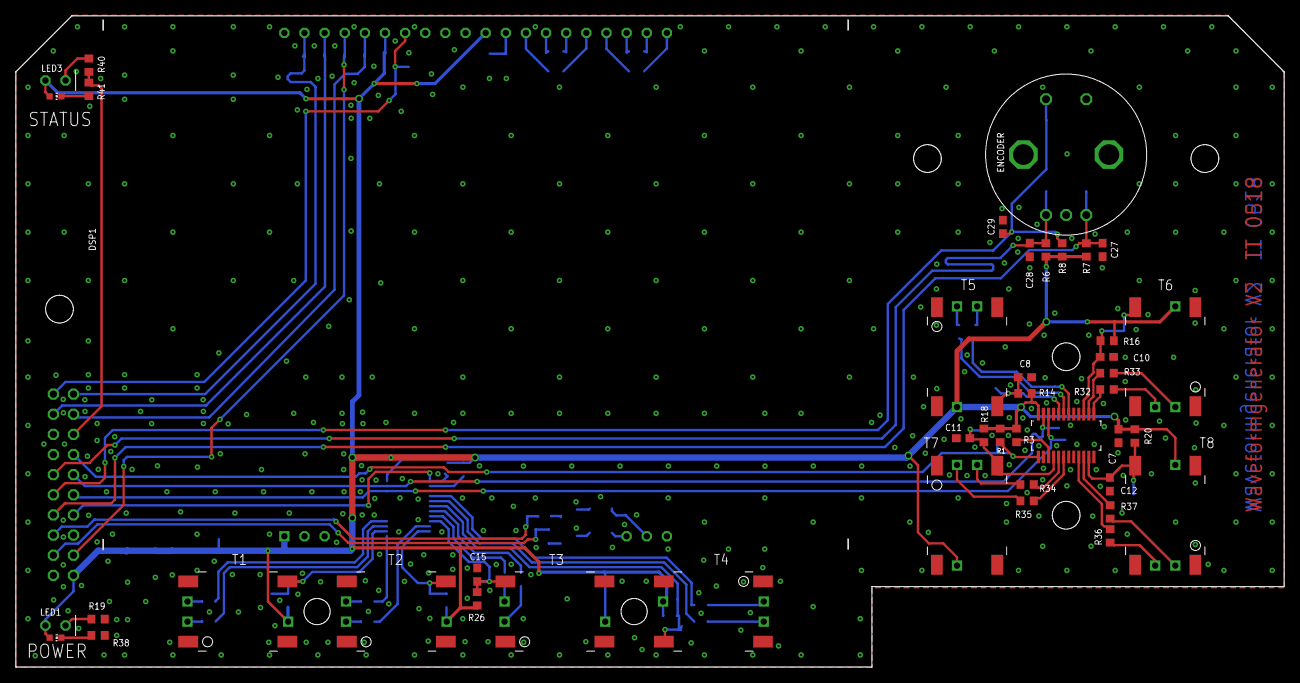
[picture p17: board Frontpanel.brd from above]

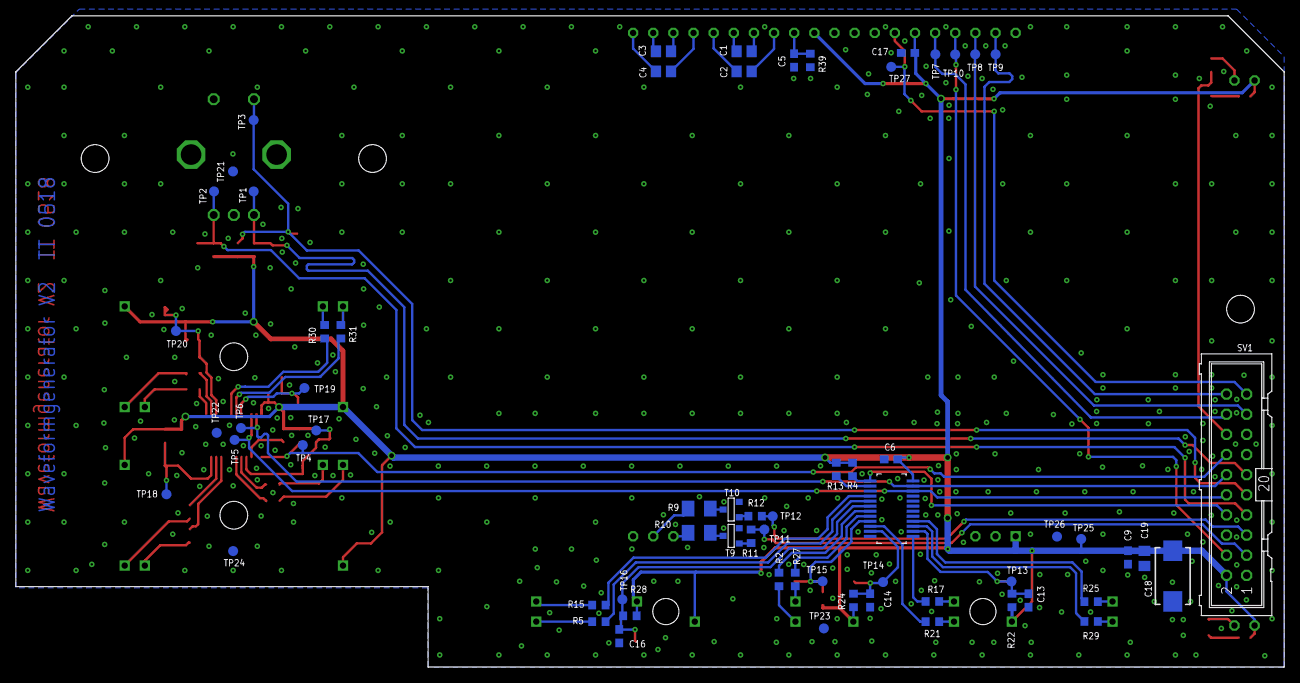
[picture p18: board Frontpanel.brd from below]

Board: 2 copper layers, 160.0 x 82.2 mm, 108 parts (64 on the bottom side), 78 nets.

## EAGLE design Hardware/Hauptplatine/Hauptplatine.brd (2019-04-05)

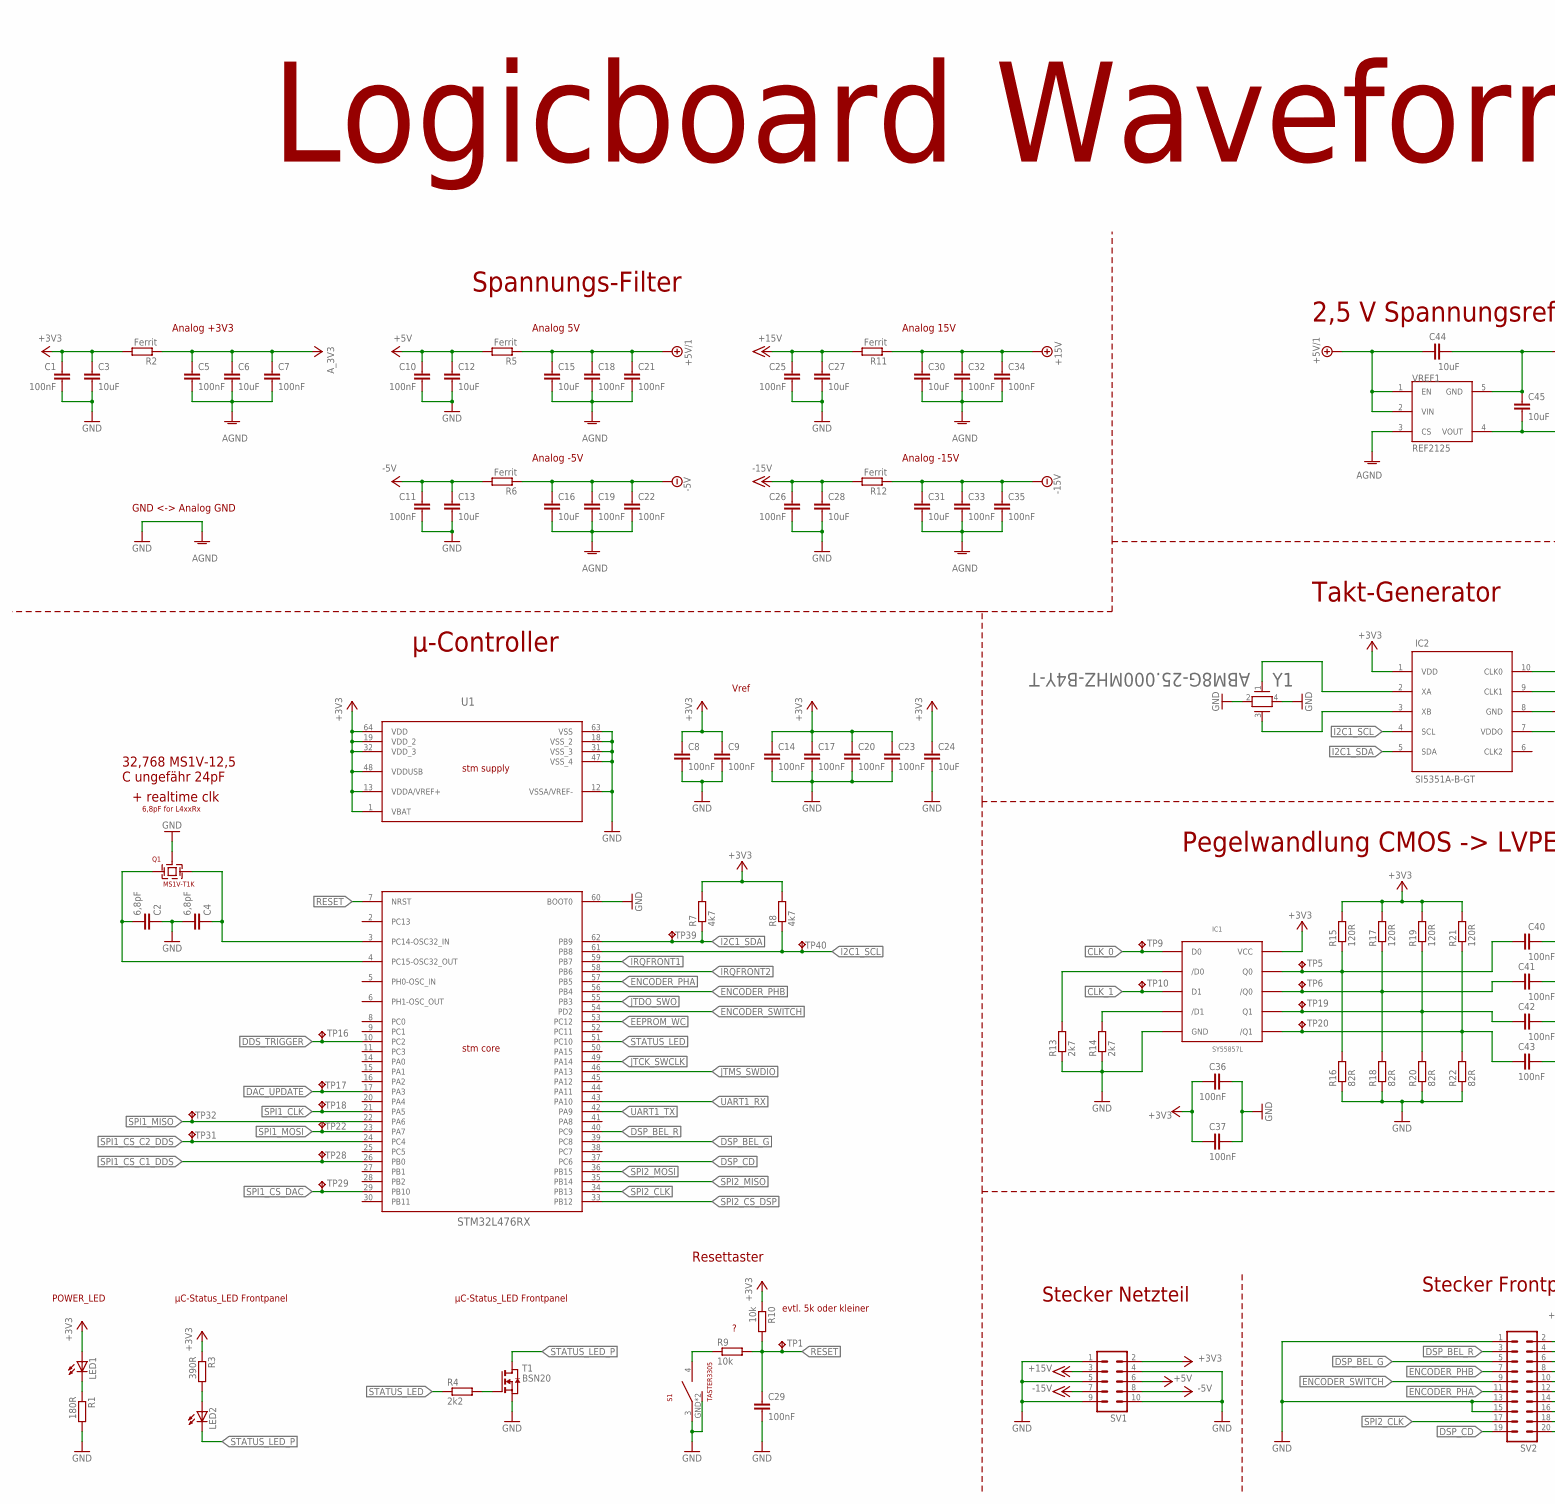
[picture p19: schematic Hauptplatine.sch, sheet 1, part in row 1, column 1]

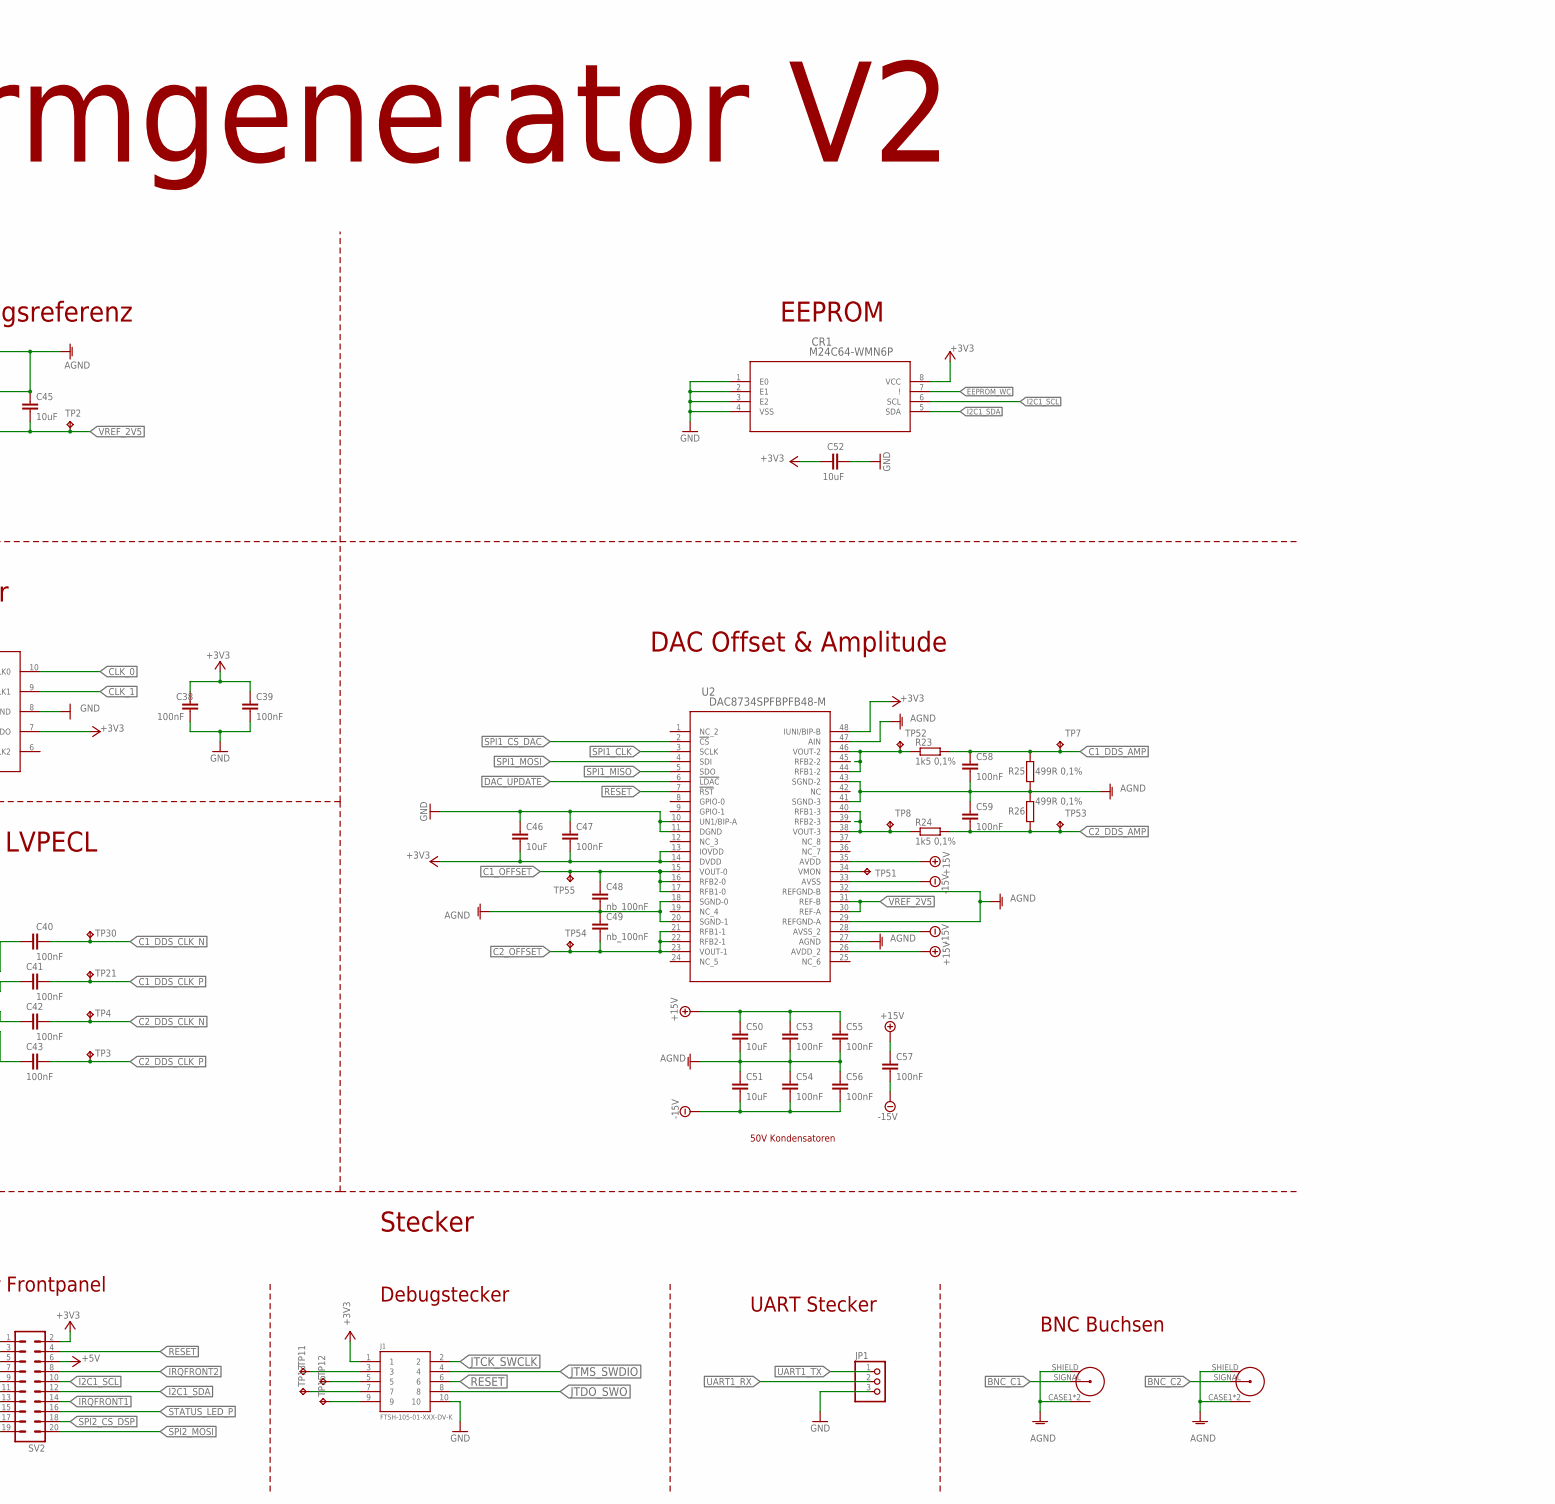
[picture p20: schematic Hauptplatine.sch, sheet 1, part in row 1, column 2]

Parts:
C1, C5, C7, C8, C9, C10, C11, C14, C17, C18, C19, C20, C21, C22, C23, C25, C26, C29, C32, C33, C34, C35, C36, C37, C38, C39, C40, C41, C42, C43, C47, C53, C54, C55, C56, C57, C58, C59: 100nF; C0603
C2, C4: 6,8pF; C0603
C3, C6, C12, C13, C15, C16, C24, C27, C28, C30, C31, C44, C45, C46, C50, C51, C52: 10uF; C0603
C48, C49: nb_100nF; C0603
CR1: M24C64-WMN6P; SO-8
IC1: SY55857L; MSOP(K10-1)
IC2: SI5351A-B-GT; MSOP10
J1: FTSH-105-01-XXX-DV-K
JP1: PINHD-1X3; 1X03
LED1, LED2: LEDCHIPLED_0603; CHIPLED_0603
Q1: MS1V-T1K
R1: 180R; R0603
R2, R5, R6, R11, R12: Ferrit; R0603
R3: 390R; R0603
R4: 2k2; R0603
R7, R8: 4k7; R0603
R9, R10: 10k; R0603
R13, R14: 2k7; R0603
R15, R17, R19, R21: 120R; R0603
R16, R18, R20, R22: 82R; R0603
R23, R24: 1k5 0,1%; R0603
R25, R26: 499R 0,1%; R0603
S1: TASTER3305
SV1: ML10
SV2: ML20
T1: BSN20; SOT-23
TP1, TP2, TP3, TP4, TP5, TP6, TP7, TP8, TP9, TP10, TP11, TP12, TP13, TP15, TP16, TP17, TP18, TP19, TP20, TP21, TP22, TP28, TP29, TP30, TP31, TP32, TP39, TP40, TP51, TP52, TP53, TP54, TP55: TPB1,27; B1,27
U1: STM32L476RX; LQFP64-10X10MM
U2: DAC8734SPFBPFB48-M; PFB48-M
VREF1: REF2125; SOT23-5L
X1, X2: 740845_BNC
Y1: ABM8G-25.000MHZ-B4Y-T; CRYSTAL_ABM8G

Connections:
+3V3: C1.1, C3.1, C8.1, C9.1, C14.1, C17.1, C20.1, C23.1, C24.1, C36.1, C37.1, C38.1, C39.1, C46.2, C47.2, C52.1, CR1.8 (VCC), IC1.VCC, IC2.1 (VDD), IC2.7 (VDDO), J1.1, LED1.A, R2.2, R3.1, R7.2, R8.2, R10.1, R15.2, R17.2, R19.2, R21.2, SV1.2, SV2.2, U1.1 (VBAT), U1.13 (VDDA/VREF+), U1.19 (VDD_2), U1.32 (VDD_3), U1.48 (VDDUSB), U1.64 (VDD), U2.13 (IOVDD), U2.14 (DVDD), U2.48 (IUNI/BIP-B); also elsewhere on the board
+5V: C10.1, C12.1, R5.2, SV1.6, SV2.6
+5V/1: C15.1, C18.1, C21.1, C44.1, R5.1, VREF1.1 (EN), VREF1.2 (VIN); also elsewhere on the board
+15V: C25.1, C27.1, R11.2, SV1.3
+18V: C30.1, C32.1, C34.1, C50.1, C53.1, C55.1, C57.1, R11.1, U2.26 (AVDD_2), U2.35 (AVDD); also elsewhere on the board
-5V: C16.1, C19.1, C22.1, R6.1; also elsewhere on the board
-5V/D: C11.1, C13.1, R6.2, SV1.8
-15V: C26.1, C28.1, R12.2, SV1.7
-18V: C31.1, C33.1, C35.1, C51.2, C54.2, C56.2, C57.2, R12.1, U2.28 (AVSS_2), U2.33 (AVSS); also elsewhere on the board
ANALOG_3V3: C5.1, C6.1, C7.1, R2.1; also elsewhere on the board
BNC_C1: X1.SIGNAL; also elsewhere on the board
BNC_C2: X2.SIGNAL; also elsewhere on the board
C1_DDS_AMP: C58.1, R23.2, R25.2, TP7.TP; also elsewhere on the board
C1_DDS_CLK_N: C40.1, TP30.TP; also elsewhere on the board
C1_DDS_CLK_P: C41.1, TP21.TP; also elsewhere on the board
C1_OFFSET: C48.1, TP55.TP, U2.15 (VOUT-0), U2.16 (RFB2-0), U2.17 (RFB1-0); also elsewhere on the board
C2_DDS_AMP: C59.2, R24.2, R26.1, TP53.TP; also elsewhere on the board
C2_DDS_CLK_N: C42.1, TP4.TP; also elsewhere on the board
C2_DDS_CLK_P: C43.1, TP3.TP; also elsewhere on the board
C2_OFFSET: C49.2, TP54.TP, U2.21 (RFB1-1), U2.22 (RFB2-1), U2.23 (VOUT-1); also elsewhere on the board
CLK_0: IC1.D0, IC2.10 (CLK0), TP9.TP
CLK_1: IC1.D1, IC2.9 (CLK1), TP10.TP
DAC_UPDATE: TP17.TP, U1.17 (PA3), U2.6 (!LDAC)
DDS_TRIGGER: TP16.TP, U1.10 (PC2); also elsewhere on the board
DSP_BEL_G: SV2.5, U1.39 (PC8)
DSP_BEL_R: SV2.3, U1.40 (PC9)
DSP_CD: SV2.19, U1.37 (PC6)
EEPROM_WC: CR1.7 (!), U1.53 (PC12)
ENCODER_PHA: SV2.11, U1.57 (PB5)
ENCODER_PHB: SV2.7, U1.56 (PB4)
ENCODER_SWITCH: SV2.9, U1.54 (PD2)
GND: C1.2, C2.1, C3.2, C4.2, C5.2, C6.2, C7.2, C8.2, C9.2, C10.2, C11.2, C12.2, C13.2, C14.2, C15.2, C16.2, C17.2, C18.2, C19.2, C20.2, C21.2, C22.2, C23.2, C24.2, C25.2, C26.2, C27.2, C28.2, C29.2, C30.2, C31.2, C32.2, C33.2, C34.2, C35.2, C36.2, C37.2, C38.2, C39.2, C44.2, C45.1, C46.1, C47.1, C48.2, C49.1, C50.2, C51.1, C52.2, C53.2, C54.1, C55.2, C56.1, C58.2, C59.1, CR1.1 (E0), CR1.2 (E1), CR1.3 (E2), CR1.4 (VSS), IC1.GND, IC2.8 (GND), J1.10, JP1.3, Q1.GND, R1.2, R13.1, R14.1, R16.1, R18.1, R20.1, R22.1, R25.1, R26.2, S1.3, S1.GND, S1.GND2 (GND), SV1.1, SV1.4, SV1.5, SV1.9, SV1.10, SV2.1, SV2.13, SV2.15, T1.2 (S), U1.12 (VSSA/VREF-), U1.18 (VSS_2), U1.31 (VSS_3), U1.47 (VSS_4), U1.60 (BOOT0), U1.63 (VSS), U2.10 (UN1/BIP-A), U2.11 (DGND), U2.18 (SGND-0), U2.20 (SGND-1), U2.27 (AGND), U2.29 (REFGND-A), U2.32 (REFGND-B), U2.41 (SGND-3), U2.43 (SGND-2), U2.47 (AIN), VREF1.3 (CS), VREF1.5 (GND), X1.CASE1 (CASE), X1.CASE2 (CASE), X1.SHIELD, X2.CASE1 (CASE), X2.CASE2 (CASE), X2.SHIELD, Y1.2, Y1.4; also elsewhere on the board
I2C1_SCL: CR1.6 (SCL), IC2.4 (SCL), R8.1, SV2.10, TP40.TP, U1.61 (PB8)
I2C1_SDA: CR1.5 (SDA), IC2.5 (SDA), R7.1, SV2.12, TP39.TP, U1.62 (PB9)
IRQFRONT1: SV2.14, U1.59 (PB7)
IRQFRONT2: SV2.8, U1.58 (PB6)
JTCK_SWCLK: J1.2, U1.49 (PA14)
JTDO_SWO: J1.8, U1.55 (PB3)
JTMS_SWDIO: J1.4, U1.46 (PA13)
unnamed: R9.1, S1.4
unnamed: LED1.C, R1.1
unnamed: R23.1, TP52.TP, U2.44 (RFB1-2), U2.45 (RFB2-2), U2.46 (VOUT-2)
unnamed: IC2.2 (XA), Y1.1
unnamed: IC2.3 (XB), Y1.3
unnamed: J1.3, TP11.TP
unnamed: R24.1, TP8.TP, U2.38 (VOUT-3), U2.39 (RFB2-3), U2.40 (RFB1-3)
unnamed: C2.2, Q1.1, U1.4 (PC15-OSC32_OUT)
unnamed: R4.2, T1.3 (G)
unnamed: LED2.A, R3.2
unnamed: J1.5, TP12.TP
unnamed: J1.7, TP13.TP
unnamed: IC1./D1, R14.2
unnamed: IC1./D0, R13.2
unnamed: C40.2, IC1.Q0, R15.1, R16.2, TP5.TP
unnamed: C41.2, IC1./Q0, R17.1, R18.2, TP6.TP
unnamed: C42.2, IC1.Q1, R19.1, R20.2, TP19.TP
unnamed: J1.9, TP15.TP
unnamed: C43.2, IC1./Q1, R21.1, R22.2, TP20.TP
unnamed: TP51.TP, U2.34 (VMON)
unnamed: C4.1, Q1.2, U1.3 (PC14-OSC32_IN)
RESET: C29.1, J1.6, R9.2, R10.2, SV2.4, TP1.TP, U1.7 (NRST), U2.7 (!RST); also elsewhere on the board
SPI1_CLK: TP18.TP, U1.21 (PA5), U2.3 (SCLK); also elsewhere on the board
SPI1_CS_C1_DDS: TP28.TP, U1.26 (PB0); also elsewhere on the board
SPI1_CS_C2_DDS: TP31.TP, U1.24 (PC4); also elsewhere on the board
SPI1_CS_DAC: TP29.TP, U1.29 (PB10), U2.2 (!CS)
SPI1_MISO: TP32.TP, U1.22 (PA6), U2.5 (SDO); also elsewhere on the board
SPI1_MOSI: TP22.TP, U1.23 (PA7), U2.4 (SDI); also elsewhere on the board
SPI2_CLK: SV2.17, U1.34 (PB13)
SPI2_CS_DSP: SV2.18, U1.33 (PB12)
SPI2_MISO: U1.35 (PB14)
SPI2_MOSI: SV2.20, U1.36 (PB15)
STATUS_LED: R4.1, U1.51 (PC10)
STATUS_LED_P: LED2.C, SV2.16, T1.1 (D)
UART1_RX: JP1.2, U1.43 (PA10)
UART1_TX: JP1.1, U1.42 (PA9)
VREF_2V5: C45.2, TP2.TP, U2.30 (REF-A), U2.31 (REF-B), VREF1.4 (VOUT)

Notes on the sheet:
Stecker Frontpanel
Debugstecker
Stecker
Spannungs-Filter
Analog -5V
Analog +3V3
Analog 5V
Analog -15V
Analog 15V
+ realtime clk
32,768 MS1V-12,5 C ungefähr 24pF
Logicboard Waveformgenerator V2
Resettaster
evtl. 5k oder kleiner
Stecker Netzteil
POWER_LED
µC-Status_LED Frontpanel
BNC Buchsen
6,8pF for L4xxRx
Vref
2,5 V Spannungsreferenz
Takt-Generator
µ-Controller
EEPROM
DAC Offset & Amplitude
50V Kondensatoren
UART Stecker
Pegelwandlung CMOS -> LVPECL
GND <-> Analog GND

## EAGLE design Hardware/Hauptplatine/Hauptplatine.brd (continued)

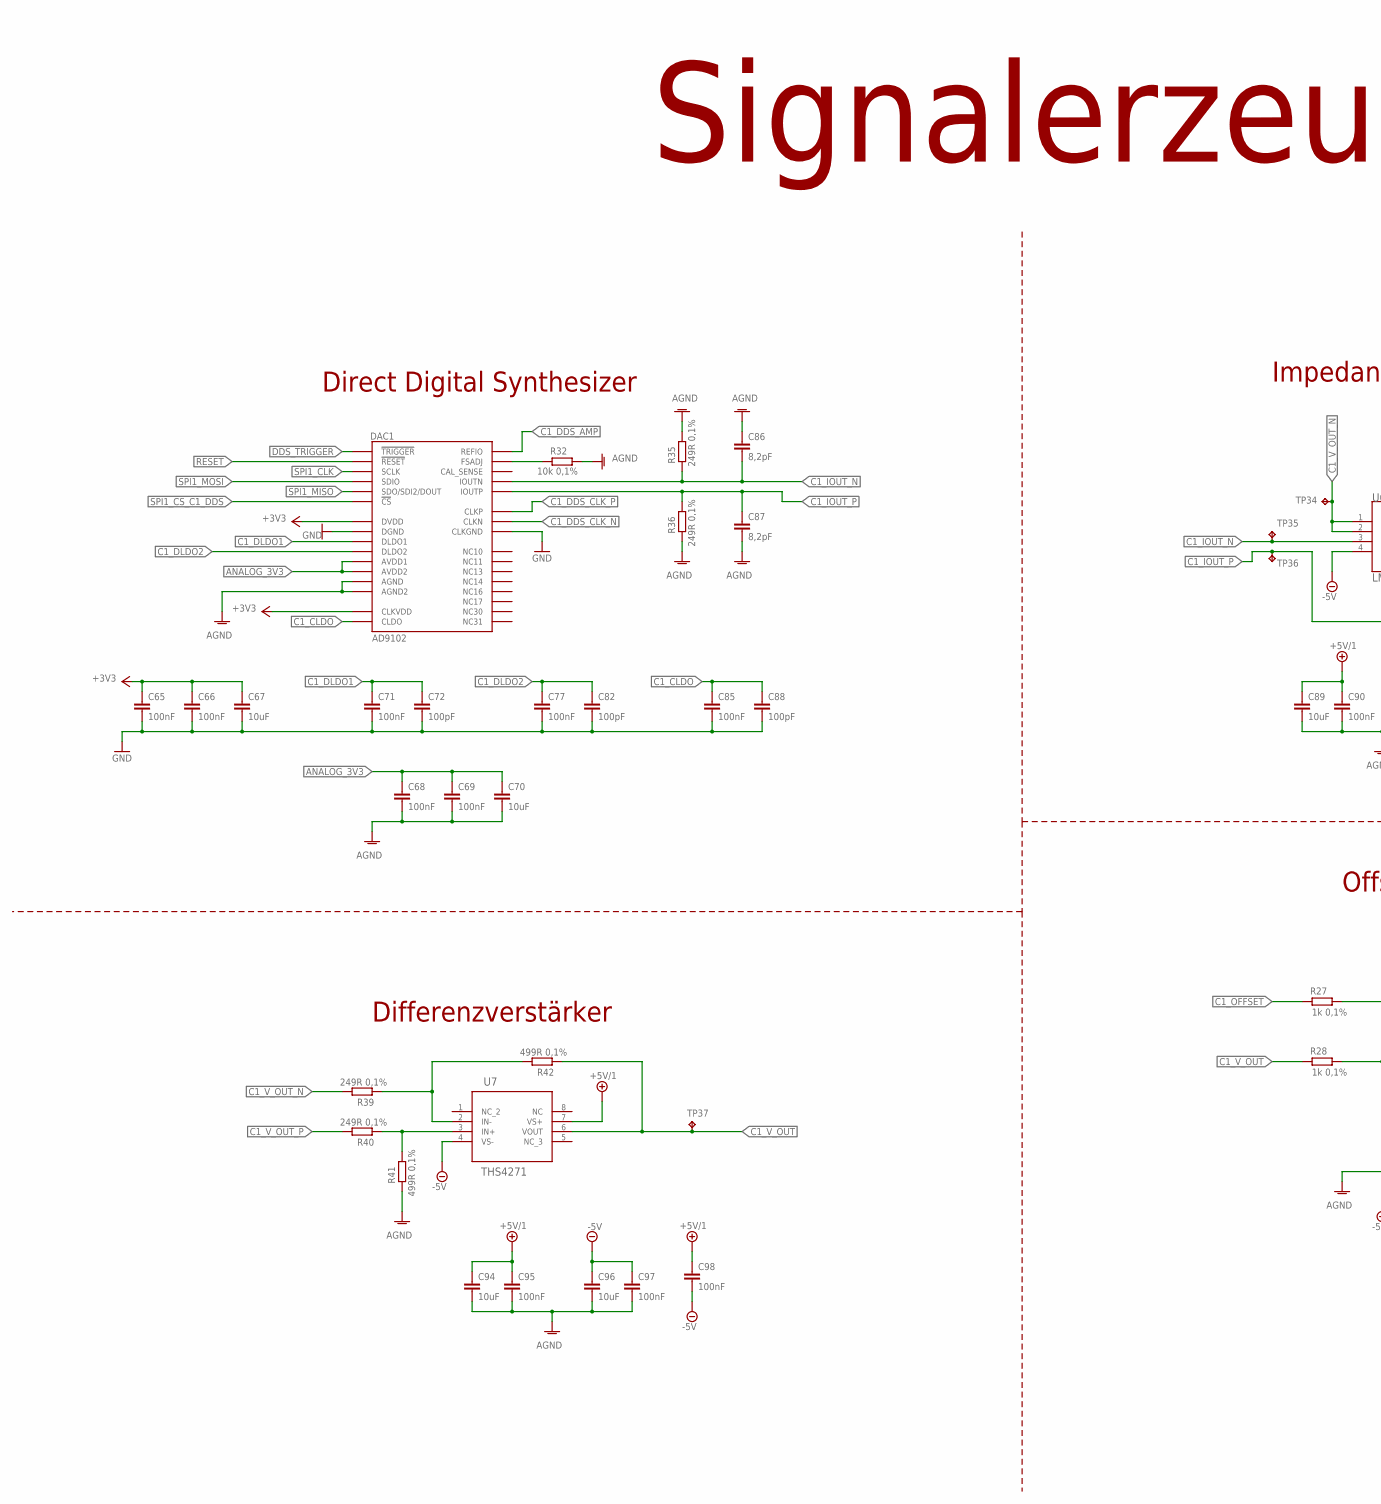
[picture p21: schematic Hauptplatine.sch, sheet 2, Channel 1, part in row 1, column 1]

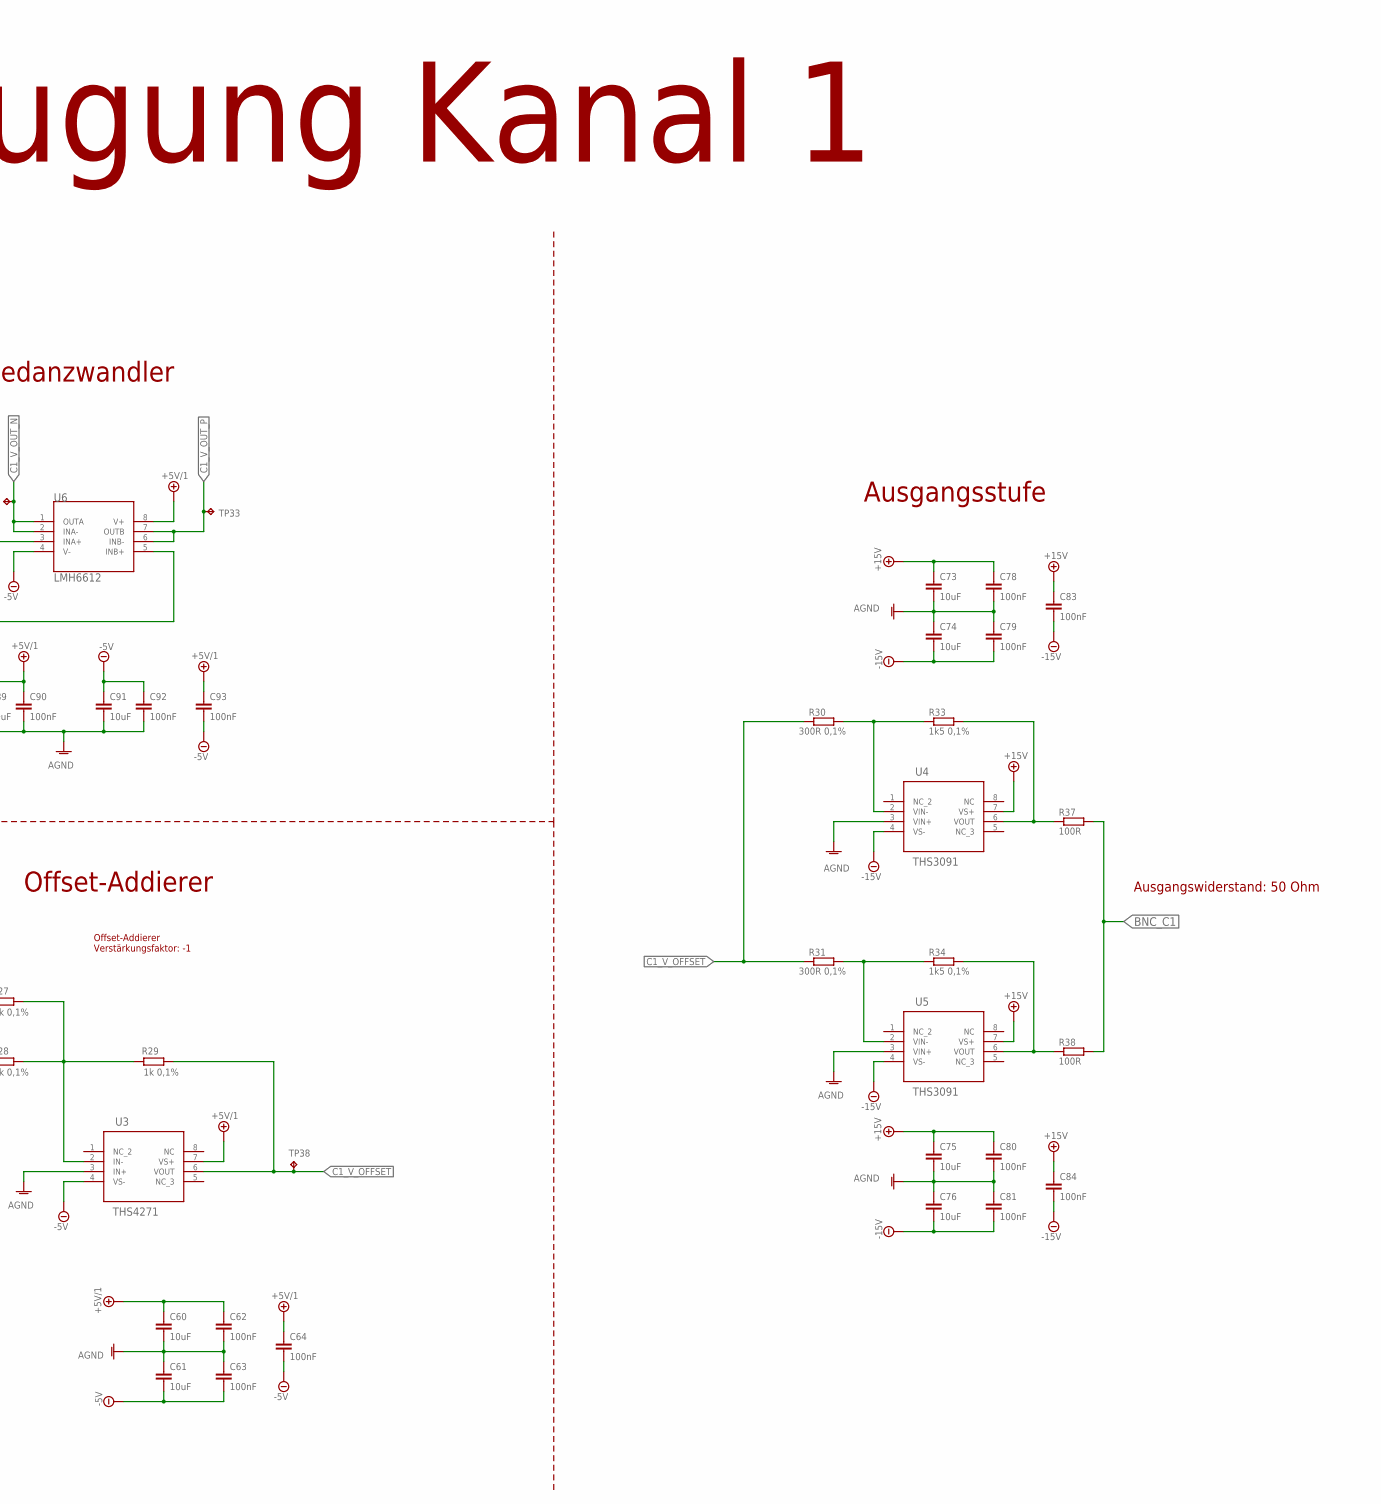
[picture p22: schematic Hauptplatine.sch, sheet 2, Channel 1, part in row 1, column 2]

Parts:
C60, C61, C67, C70, C73, C74, C75, C76, C89, C91, C94, C96: 10uF; C0603
C62, C63, C64, C65, C66, C68, C69, C71, C77, C78, C79, C80, C81, C83, C84, C85, C90, C92, C93, C95, C97, C98: 100nF; C0603
C72, C82, C88: 100pF; C0603
C86, C87: 8,2pF; C0603
DAC1: AD9102; CP_32_12
R27, R28, R29: 1k 0,1%; R0603
R30, R31: 300R 0,1%; R0603
R32: 10k 0,1%; R0603
R33, R34: 1k5 0,1%; R0603
R35, R36, R39, R40: 249R 0,1%; R0603
R37, R38: 100R; R0603
R41, R42: 499R 0,1%; R0603
TP33, TP34, TP35, TP36, TP37, TP38: TPB1,27; B1,27
U3, U7: THS4271; D8-M
U4, U5: THS3091; D8-M
U6: LMH6612; M08A-M

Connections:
+3V3: C65.1, C66.1, C67.1, DAC1.5 (DVDD), DAC1.23 (CLKVDD); also elsewhere on the board
+5V/1: C60.1, C62.1, C64.1, C89.1, C90.1, C93.1, C94.1, C95.1, C98.1, U3.7 (VS+), U6.8 (V+), U7.7 (VS+); also elsewhere on the board
+18V: C73.1, C75.1, C78.1, C80.1, C83.1, C84.1, U4.7 (VS+), U5.7 (VS+); also elsewhere on the board
-5V: C61.2, C63.2, C64.2, C91.1, C92.1, C93.2, C96.1, C97.1, C98.2, U3.4 (VS-), U6.4 (V-), U7.4 (VS-); also elsewhere on the board
-18V: C74.2, C76.2, C79.2, C81.2, C83.2, C84.2, U4.4 (VS-), U5.4 (VS-); also elsewhere on the board
ANALOG_3V3: C68.1, C69.1, C70.1, DAC1.12 (AVDD2), DAC1.29 (AVDD1); also elsewhere on the board
BNC_C1: R37.2, R38.2; also elsewhere on the board
C1_CLDO: C85.1, C88.1, DAC1.22 (CLDO)
C1_DDS_AMP: DAC1.18 (REFIO); also elsewhere on the board
C1_DDS_CLK_N: DAC1.20 (CLKN); also elsewhere on the board
C1_DDS_CLK_P: DAC1.21 (CLKP); also elsewhere on the board
C1_DLDO1: C71.1, C72.1, DAC1.6 (DLDO1)
C1_DLDO2: C77.1, C82.1, DAC1.4 (DLDO2)
C1_IOUT_N: C86.2, DAC1.28 (IOUTN), R35.1, TP35.TP, U6.3 (INA+)
C1_IOUT_P: C87.1, DAC1.27 (IOUTP), R36.2, TP36.TP, U6.5 (INB+)
C1_OFFSET: R27.2; also elsewhere on the board
C1_V_OFFSET: R29.1, R30.1, R31.1, TP38.TP, U3.6 (VOUT)
C1_V_OUT: R28.2, R42.1, TP37.TP, U7.6 (VOUT)
C1_V_OUT_N: R39.2, TP34.TP, U6.1 (OUTA), U6.2 (INA-)
C1_V_OUT_P: R40.2, TP33.TP, U6.6 (INB-), U6.7 (OUTB)
DDS_TRIGGER: DAC1.32 (!TRIGGER); also elsewhere on the board
GND: C60.2, C61.1, C62.2, C63.1, C65.2, C66.2, C67.2, C68.2, C69.2, C70.2, C71.2, C72.2, C73.2, C74.1, C75.2, C76.1, C77.2, C78.2, C79.1, C80.2, C81.1, C82.2, C85.2, C86.1, C87.2, C88.2, C89.2, C90.2, C91.2, C92.2, C94.2, C95.2, C96.2, C97.2, DAC1.3 (DGND), DAC1.15 (AGND), DAC1.19 (CLKGND), DAC1.26 (AGND2), DAC1.33 (DGND), R32.2, R35.2, R36.1, R41.1, U3.3 (IN+), U4.3 (VIN+), U5.3 (VIN+); also elsewhere on the board
unnamed: DAC1.25 (FSADJ), R32.1
unnamed: R40.1, R41.2, U7.3 (IN+)
unnamed: R39.1, R42.2, U7.2 (IN-)
unnamed: R33.2, R37.1, U4.6 (VOUT)
unnamed: R31.2, R34.1, U5.2 (VIN-)
unnamed: R34.2, R38.1, U5.6 (VOUT)
unnamed: R30.2, R33.1, U4.2 (VIN-)
unnamed: R27.1, R28.1, R29.2, U3.2 (IN-)
RESET: DAC1.9 (!RESET); also elsewhere on the board
SPI1_CLK: DAC1.1 (SCLK); also elsewhere on the board
SPI1_CS_C1_DDS: DAC1.8 (!CS); also elsewhere on the board
SPI1_MISO: DAC1.7 (SDO/SDI2/DOUT); also elsewhere on the board
SPI1_MOSI: DAC1.2 (SDIO); also elsewhere on the board

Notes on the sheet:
Signalerzeugung Kanal 1
Direct Digital Synthesizer
Differenzverstärker
Offset-Addierer
Ausgangsstufe
Offset-Addierer Verstärkungsfaktor: -1
Impedanzwandler
Ausgangswiderstand: 50 Ohm

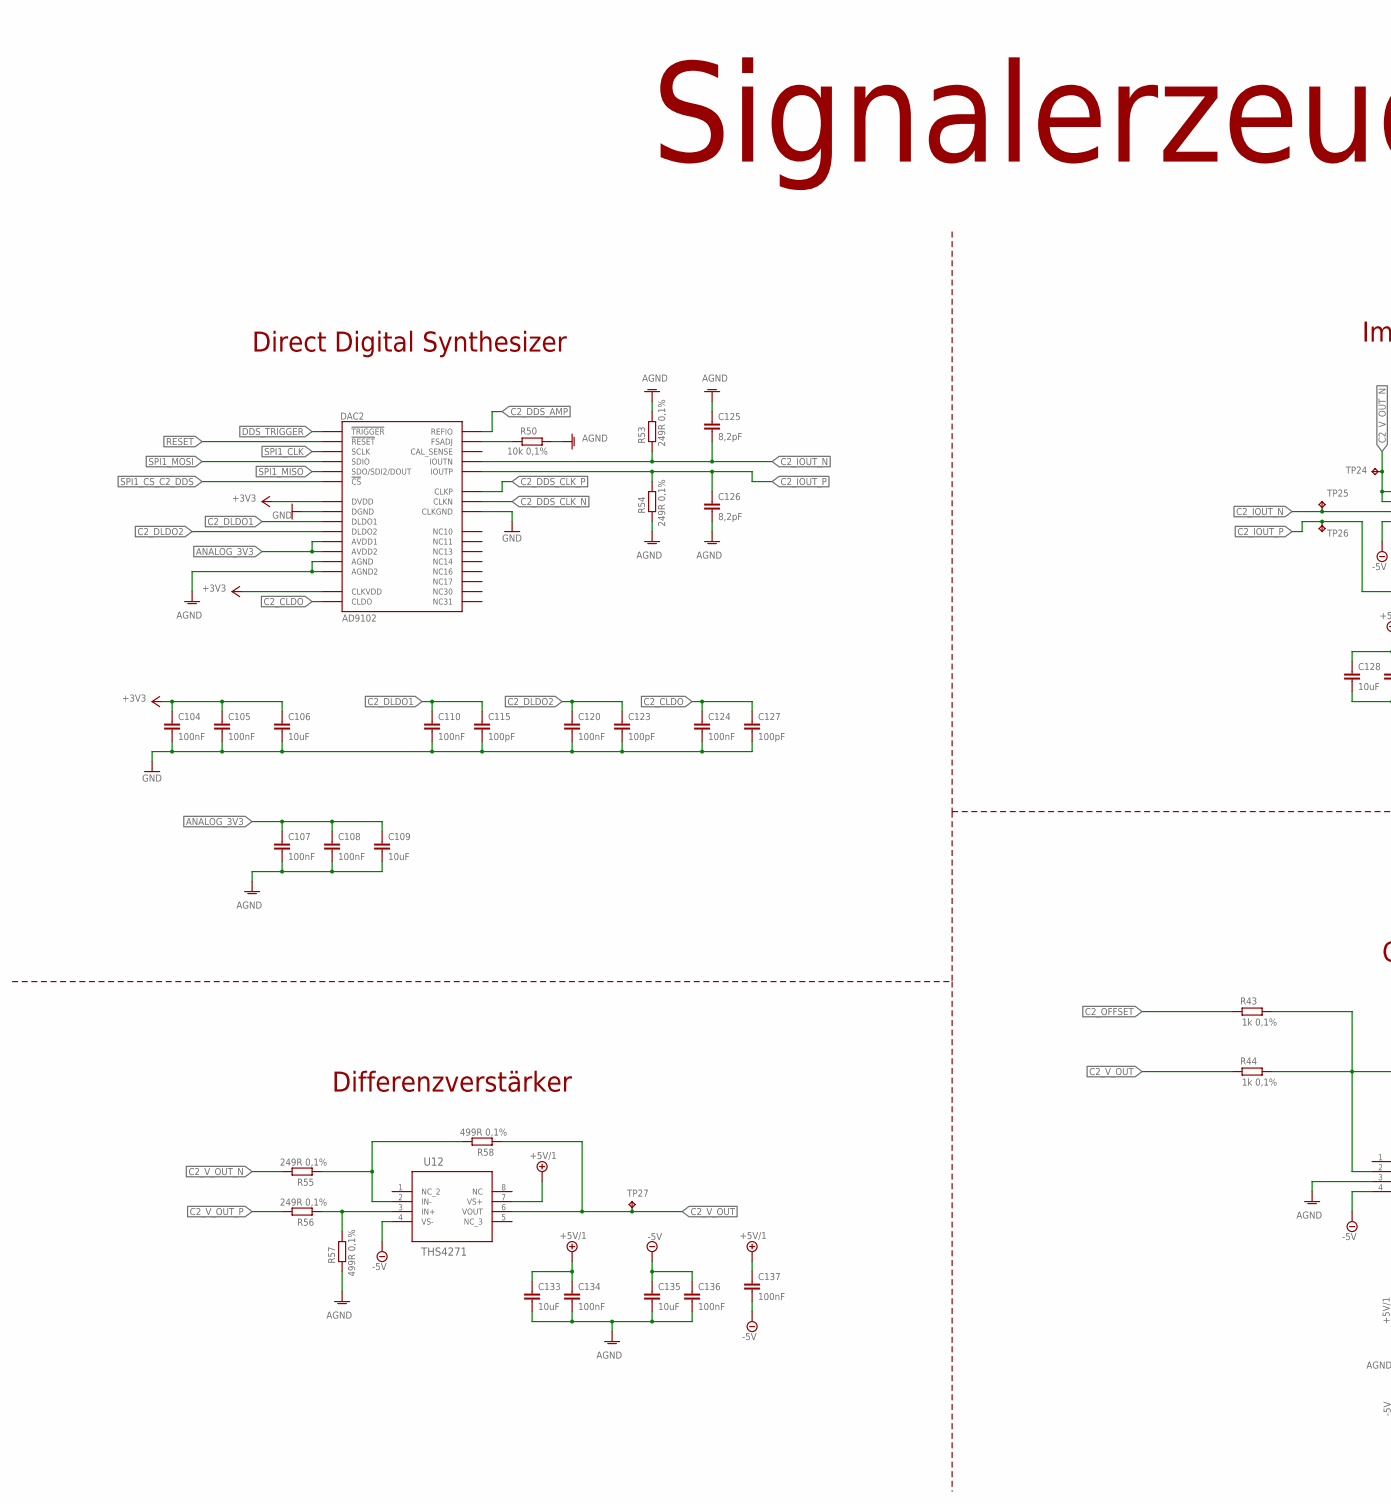
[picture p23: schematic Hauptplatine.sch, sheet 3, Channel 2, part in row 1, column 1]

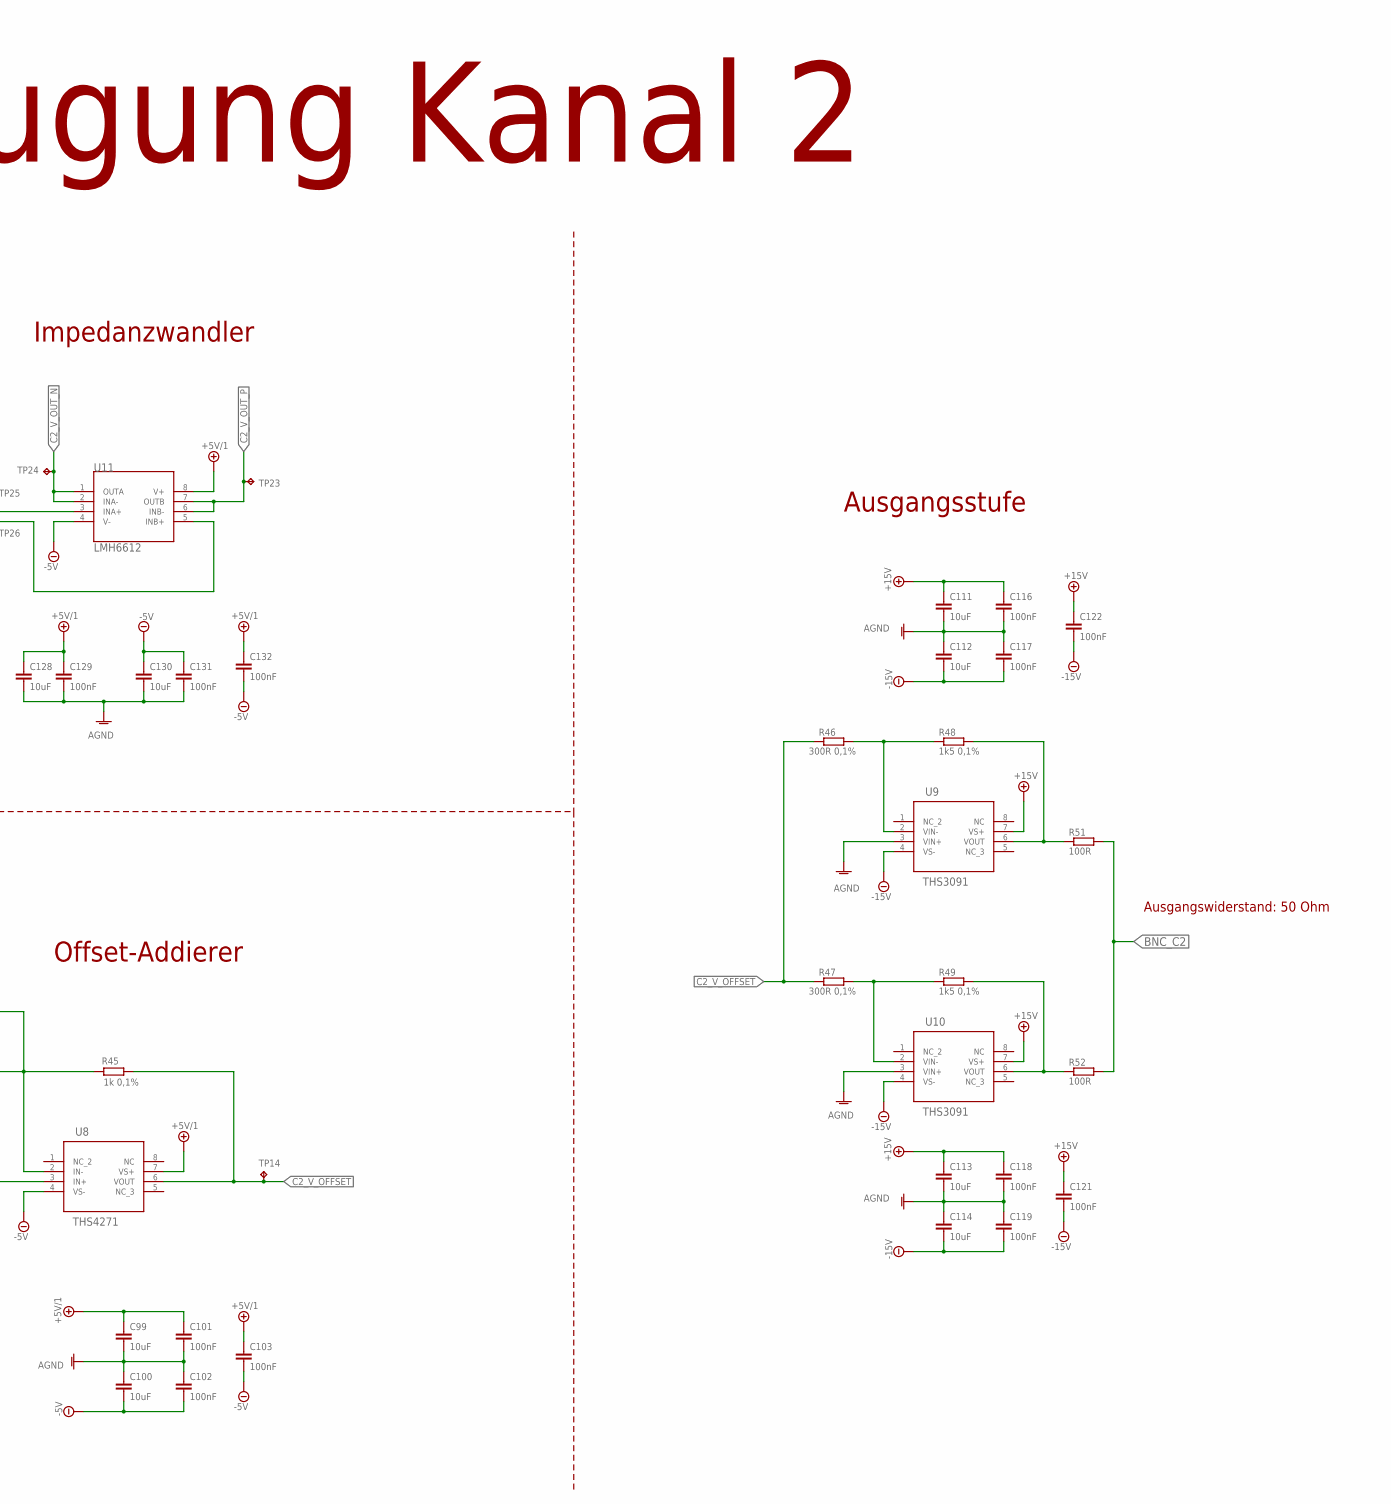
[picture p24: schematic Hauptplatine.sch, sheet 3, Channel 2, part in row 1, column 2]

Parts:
C99, C100, C106, C109, C111, C112, C113, C114, C128, C130, C133, C135: 10uF; C0603
C101, C102, C103, C104, C105, C107, C108, C110, C116, C117, C118, C119, C120, C121, C122, C124, C129, C131, C132, C134, C136, C137: 100nF; C0603
C115, C123, C127: 100pF; C0603
C125, C126: 8,2pF; C0603
DAC2: AD9102; CP_32_12
R43, R44, R45: 1k 0,1%; R0603
R46, R47: 300R 0,1%; R0603
R48, R49: 1k5 0,1%; R0603
R50: 10k 0,1%; R0603
R51, R52: 100R; R0603
R53, R54, R55, R56: 249R 0,1%; R0603
R57, R58: 499R 0,1%; R0603
TP14, TP23, TP24, TP25, TP26, TP27: TPB1,27; B1,27
U8, U12: THS4271; D8-M
U9, U10: THS3091; D8-M
U11: LMH6612; M08A-M

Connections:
+3V3: C104.1, C105.1, C106.1, DAC2.5 (DVDD), DAC2.23 (CLKVDD); also elsewhere on the board
+5V/1: C99.1, C101.1, C103.1, C128.1, C129.1, C132.1, C133.1, C134.1, C137.1, U8.7 (VS+), U11.8 (V+), U12.7 (VS+); also elsewhere on the board
+18V: C111.1, C113.1, C116.1, C118.1, C121.1, C122.1, U9.7 (VS+), U10.7 (VS+); also elsewhere on the board
-5V: C100.2, C102.2, C103.2, C130.1, C131.1, C132.2, C135.1, C136.1, C137.2, U8.4 (VS-), U11.4 (V-), U12.4 (VS-); also elsewhere on the board
-18V: C112.2, C114.2, C117.2, C119.2, C121.2, C122.2, U9.4 (VS-), U10.4 (VS-); also elsewhere on the board
ANALOG_3V3: C107.1, C108.1, C109.1, DAC2.12 (AVDD2), DAC2.29 (AVDD1); also elsewhere on the board
BNC_C2: R51.2, R52.2; also elsewhere on the board
C2_CLDO: C124.1, C127.1, DAC2.22 (CLDO)
C2_DDS_AMP: DAC2.18 (REFIO); also elsewhere on the board
C2_DDS_CLK_N: DAC2.20 (CLKN); also elsewhere on the board
C2_DDS_CLK_P: DAC2.21 (CLKP); also elsewhere on the board
C2_DLDO1: C110.1, C115.1, DAC2.6 (DLDO1)
C2_DLDO2: C120.1, C123.1, DAC2.4 (DLDO2)
C2_IOUT_N: C125.2, DAC2.28 (IOUTN), R53.1, TP25.TP, U11.3 (INA+)
C2_IOUT_P: C126.1, DAC2.27 (IOUTP), R54.2, TP26.TP, U11.5 (INB+)
C2_OFFSET: R43.2; also elsewhere on the board
C2_V_OFFSET: R45.1, R46.1, R47.1, TP14.TP, U8.6 (VOUT)
C2_V_OUT: R44.2, R58.1, TP27.TP, U12.6 (VOUT)
C2_V_OUT_N: R55.2, TP24.TP, U11.1 (OUTA), U11.2 (INA-)
C2_V_OUT_P: R56.2, TP23.TP, U11.6 (INB-), U11.7 (OUTB)
DDS_TRIGGER: DAC2.32 (!TRIGGER); also elsewhere on the board
GND: C99.2, C100.1, C101.2, C102.1, C104.2, C105.2, C106.2, C107.2, C108.2, C109.2, C110.2, C111.2, C112.1, C113.2, C114.1, C115.2, C116.2, C117.1, C118.2, C119.1, C120.2, C123.2, C124.2, C125.1, C126.2, C127.2, C128.2, C129.2, C130.2, C131.2, C133.2, C134.2, C135.2, C136.2, DAC2.3 (DGND), DAC2.15 (AGND), DAC2.19 (CLKGND), DAC2.26 (AGND2), DAC2.33 (DGND), R50.2, R53.2, R54.1, R57.1, U8.3 (IN+), U9.3 (VIN+), U10.3 (VIN+); also elsewhere on the board
unnamed: DAC2.25 (FSADJ), R50.1
unnamed: R56.1, R57.2, U12.3 (IN+)
unnamed: R55.1, R58.2, U12.2 (IN-)
unnamed: R48.2, R51.1, U9.6 (VOUT)
unnamed: R47.2, R49.1, U10.2 (VIN-)
unnamed: R49.2, R52.1, U10.6 (VOUT)
unnamed: R46.2, R48.1, U9.2 (VIN-)
unnamed: R43.1, R44.1, R45.2, U8.2 (IN-)
RESET: DAC2.9 (!RESET); also elsewhere on the board
SPI1_CLK: DAC2.1 (SCLK); also elsewhere on the board
SPI1_CS_C2_DDS: DAC2.8 (!CS); also elsewhere on the board
SPI1_MISO: DAC2.7 (SDO/SDI2/DOUT); also elsewhere on the board
SPI1_MOSI: DAC2.2 (SDIO); also elsewhere on the board

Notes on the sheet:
Signalerzeugung Kanal 2
Direct Digital Synthesizer
Differenzverstärker
Ausgangsstufe
Offset-Addierer
Impedanzwandler
Ausgangswiderstand: 50 Ohm

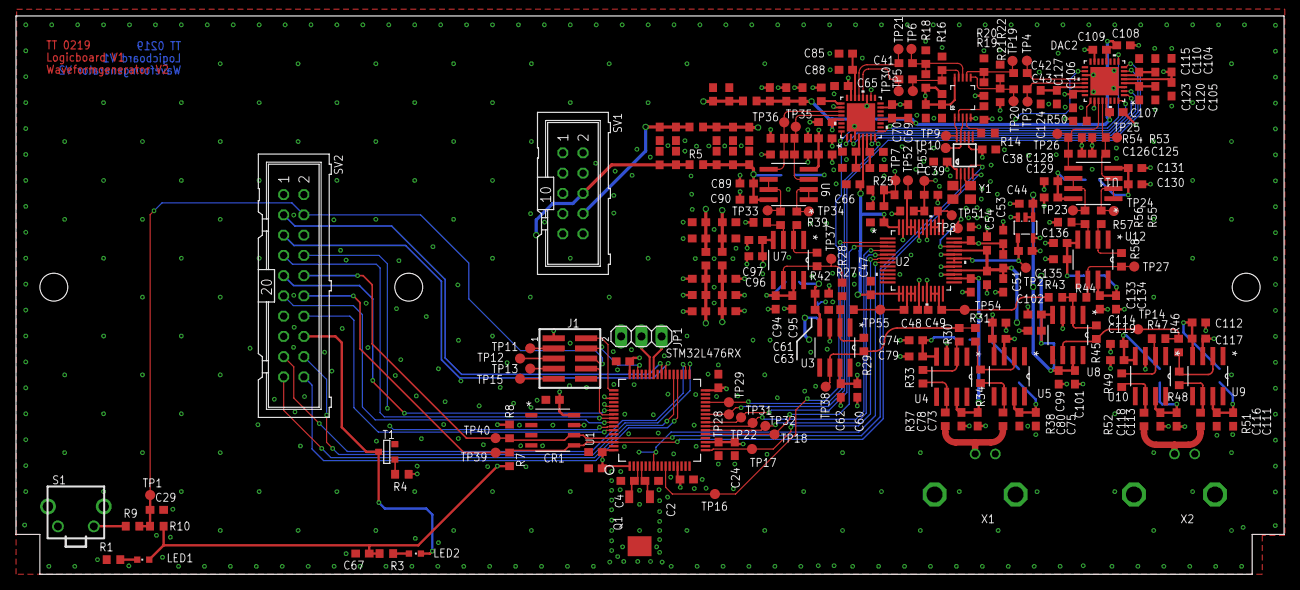
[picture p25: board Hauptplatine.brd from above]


Board: 4 copper layers, 159.0 x 70.0 mm, 270 parts (10 on the bottom side), 109 nets.

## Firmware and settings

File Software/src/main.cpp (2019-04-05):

#include <chrono>
#include <functional>

#include "SystemManager.h"
#include "ChannelMenu.h"
#include "MainMenu.h"
#include "BootscreenMenu.h"
#include "MenuController.h"


using namespace std::chrono_literals;

int main(void)
{
	/* Create a reference to the system */
	auto& system_ = System::instance();

	/* Create objects for UserInterface */
	Interface::MenuController<Interface::MenuNames::Menu_Count> menuController_(system_);
	Interface::MainMenu mainmenu_("Mainmenu", system_, 0x0001);
	Interface::ChannelMenu channel1_("Channel 1", SignalGeneration::Output::Ch1, system_, 0x0002);
	Interface::ChannelMenu channel2_("Channel 2", SignalGeneration::Output::Ch2, system_, 0x0003);
	Interface::BootscreenMenu bootscreen_("Waveformgenerator 2.0", system_);


	/* Reset display */
	system_.display().reset();

	/* Delayed initialisation of further components */
	system_.timer().asyncWait(150ms, [&](){

		/* Create a reference to the system */
		auto& system_ = System::instance();

		/* Start a heartbeat signal to pulse the status LEDs */
		system_.heartbeat().init(500ms);

		/* 	Create a new Pin map object for the port expander
		 * 	Will be copied into the button array, so we can delete this object at the
		 * 	end of the initialize() method
		 * 	This object will be used for both FourButtonArrays:
		 * 	first we set the pin values for the first portExpander, copy the map in
		 * 	the local storage in the class and then modify the pin values for the
		 * 	second portExpander
		 */
		System::FourButtonArray::PinMap portExpanderPinMap;

		portExpanderPinMap.Button1Press	= 9;
		portExpanderPinMap.Button1Red	= 11;
		portExpanderPinMap.Button1Green = 10;
		portExpanderPinMap.Button2Press	= 7;
		portExpanderPinMap.Button2Red	= 8;
		portExpanderPinMap.Button2Green = 6;
		portExpanderPinMap.Button3Press	= 5;
		portExpanderPinMap.Button3Red	= 4;
		portExpanderPinMap.Button3Green = 3;
		portExpanderPinMap.Button4Press	= 2;
		portExpanderPinMap.Button4Red	= 1;
		portExpanderPinMap.Button4Green = 0;
		system_.displayButtons().initialize(portExpanderPinMap);

		/* Modify pinMap for portExpander 2 */
		portExpanderPinMap.Button1Press	= 15;
		portExpanderPinMap.Button1Red	= 13;
		portExpanderPinMap.Button1Green = 14;
		portExpanderPinMap.Button2Press	= 10;
		portExpanderPinMap.Button2Red	= 8;
		portExpanderPinMap.Button2Green = 9;
		portExpanderPinMap.Button3Press	= 0;
		portExpanderPinMap.Button3Red	= 1;
		portExpanderPinMap.Button3Green = 2;
		portExpanderPinMap.Button4Press	= 7;
		portExpanderPinMap.Button4Red	= 5;
		portExpanderPinMap.Button4Green = 6;
		system_.channelButtons().initialize(portExpanderPinMap);

		/* Initialize the display */
		system_.display().init();

		menuController_.addMenu(&mainmenu_, Interface::MenuNames::_Mainmenu);
		menuController_.addMenu(&channel1_, Interface::MenuNames::_Channel1);
		menuController_.addMenu(&channel2_, Interface::MenuNames::_Channel2);
		menuController_.addMenu(&bootscreen_, Interface::MenuNames::_Bootscreen);
		menuController_.changeMenuTo(Interface::MenuNames::_Bootscreen);
	});

	system_.timer().asyncWait(250ms, [&](){
		system_.frequencyController().initialize();;
	});


	system_.timer().asyncWait(550ms, [&](){
		/* Initialize the menus and add them to the controller */
		mainmenu_.init();
	});

	system_.timer().asyncWait(850ms, [&](){
		channel1_.init();
	});

	system_.timer().asyncWait(1150ms, [&](){
		channel2_.init();
	});


	/* Change to main menu after 3 seconds in the boot screen */
	system_.timer().asyncWait(3s, [&](){
		menuController_.init();
		menuController_.changeMenuTo(Interface::MenuNames::_Mainmenu);

	});

	/* Start main program execution */
	system_.eventLoop().run();
}

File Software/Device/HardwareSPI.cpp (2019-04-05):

#include <HardwareSPI.h>
#include <cstdint>
#include <functional>
#include "stm32l476xx.h"
#include "HardwareCore.h"

//---------------------------------------------------------------------------------------
// -------------------- Implementation of Class 'HardwareSPI' --------------------------


Device::HardwareSPI::
HardwareSPI(SPI_TypeDef* base) :
	spiBase_(base),
	currentClkPhase_(ClockPhase::FirstEdge)
{
	/* Local variables for respective pins */
	uint8_t pinSCK_ = 0;
	uint8_t pinMOSI_ = 0;
	uint8_t pinMISO_ = 0;

	DMA_Request_TypeDef* dmaCSELR_;

	/*SPI clk divider
	 *
	 * 	000: fPCLK/2
	 *	001: fPCLK/4
	 *	010: fPCLK/8
	 *	011: fPCLK/16
	 *	100: fPCLK/32
	 *	101: fPCLK/64
	 *  110: fPCLK/128
	 *	111: fPCLK/256
	 */
	uint8_t SPI_fclk_div = 0;

	if(spiBase_ == SPI1) {
		/* SPI1:
		 * 		GPIO	(PA4		SPI1_NSS)
		 * 				PA5			SPI1_SCK
		 * 				PA6			SPI1_MISO
		 * 				PA7			SPI1_MOSI
		 *
		 * 		DMA 1	Channel 2 	SPI1_RX
		 * 				Channel 3	SPI1_TX
		 */

		/* Enable Clock for GPIOA */
		RCC->AHB2ENR		|= 0x01<<0;
		/* Enable Clock for DMA1 */
		RCC->AHB1ENR		|= 0x01<<0;
		/* Enable Clock for SPI1 */
		RCC->APB2ENR 		|= 0x01<<12;

		/* Set Hardware Devices for SPI1 */
		gpioBase_ = GPIOA;
		pinSCK_ = 5;
		pinMOSI_ = 7;
		pinMISO_ = 6;

		dmaBase_ = DMA1;
		dmaRX_ = DMA1_Channel2;
		dmaTX_ = DMA1_Channel3;
		dmaChRX_ = 2;
		dmaChTX_ = 3;

		SPI_fclk_div = 4;


		/* Configure SPI1 Interrupts */
		Device::InterruptMgr::reference().addHandlerForInterrupt(Device::InterruptId::SPI1_Int, [this]() { this->spiHandler(); });

		/* Configure DMA interrupts */
		Device::InterruptMgr::reference().addHandlerForInterrupt(Device::InterruptId::DMA1_CH3Int, [this]() { this->dmaTxHandler(); });
		Device::InterruptMgr::reference().addHandlerForInterrupt(Device::InterruptId::DMA1_CH2Int, [this]() { this->dmaRxHandler(); });

		dmaCSELR_ = DMA1_CSELR;
	}
	else if(spiBase_ == SPI2) {
		/* SPI2:
		 *
		 * 		GPIO	(PB12		SPI2_NSS)
		 * 				PB13		SPI2_SCK
		 * 				PB14		SPI2_MISO
		 * 				PB15		SPI2_MOSI
		 *
		 * 		DMA 1	Channel 4	SPI2_RX
		 * 				Channel 5	SPI2_TX
		 */

		/* Enable Clock for GPIOB */
		RCC->AHB2ENR		|= 0x01<<1;
		/* Enable Clock for DMA1 */
		RCC->AHB1ENR		|= 0x01<<0;
		/* Enable Clock for SPI2 */
		RCC->APB1ENR1 		|= 0x01<<14;

		/* Set Hardware Devices for SPI1 */
		gpioBase_ = GPIOB;
		pinSCK_ = 13;
		pinMOSI_ = 15;
		pinMISO_ = 14;

		dmaBase_ = DMA1;
		dmaRX_ = DMA1_Channel4;
		dmaTX_ = DMA1_Channel5;
		dmaChRX_ = 4;
		dmaChTX_ = 5;

		SPI_fclk_div = 4;

		/* Configure SPI2 Interrupts */
		Device::InterruptMgr::reference().addHandlerForInterrupt(Device::InterruptId::SPI2_Int, [this]() { this->spiHandler(); });

		/* Configure DMA interrupts */
		Device::InterruptMgr::reference().addHandlerForInterrupt(Device::InterruptId::DMA1_CH5Int, [this]() { this->dmaTxHandler(); });
		Device::InterruptMgr::reference().addHandlerForInterrupt(Device::InterruptId::DMA1_CH4Int, [this]() { this->dmaRxHandler(); });

		dmaCSELR_ = DMA1_CSELR;
	}

	/* From Here on initialisation for all SPIs is equal */
	/* Configure GPIO */
	gpioBase_->MODER		&= ~(0x03<<(pinSCK_*2) | 0x03<<(pinMOSI_*2) | 0x03<<(pinMISO_*2));
	gpioBase_->MODER		|= (0x02<<(pinSCK_*2) | 0x02<<(pinMOSI_*2) | 0x02<<(pinMISO_*2));	//Set Alternate function
	gpioBase_->OTYPER		&= ~(0x01<<(pinSCK_) | 0x01<<(pinMOSI_) | 0x01<<(pinMISO_));		//Push-Pull Configuration
	gpioBase_->OSPEEDR		|= (0x03<<(pinSCK_*2) | 0x03<<(pinMOSI_*2) | 0x03<<(pinMISO_*2));	//Output Speed Very High
	gpioBase_->PUPDR		&= ~(0x03<<(pinSCK_*2) | 0x03<<(pinMOSI_*2) | 0x03<<(pinMISO_*2));	//No Pull Resistors

	if(pinMOSI_ < 8) {
		gpioBase_->AFR[0]	|= 0x05<<(pinMOSI_*4);		//Select AF5 (SPI)
	}
	else {
		gpioBase_->AFR[1]	|= 0x05<<((pinMOSI_-8)*4);
	}

	if(pinSCK_ < 8) {
		gpioBase_->AFR[0]	|= 0x05<<(pinSCK_ *4);		//Select AF5 (SPI)
	}
	else {
		gpioBase_->AFR[1]	|= 0x05<<((pinSCK_ -8)*4);
	}

	if(pinMISO_ < 8) {
		gpioBase_->AFR[0]	|= 0x05<<(pinMISO_*4);		//Select AF5 (SPI)
	}
	else {
		gpioBase_->AFR[1]	|= 0x05<<((pinMISO_-8)*4);
	}

	/* Configuration DMA */
	std::uint8_t MemPerphSize = 0x00;

	switch(sizeof(DataType)) {
		case 1:		MemPerphSize = 0x00; 	break;
		case 2:		MemPerphSize = 0x01; 	break;
		case 4:		MemPerphSize = 0x02; 	break;
		default:	MemPerphSize = 0x00; 	break;
	}

	/*	Configure DMA RX Channel
	 * Medium Prio,
	 * 8, 16, 32 Bit Memory depending on size of Datatype,
	 * 8, 16, 32 Bit Peripherial depending on size of Datatype,
	 * Memory increment mode,
	 * Transfer error interrupt
	 * Transfer complete interrupt
	 * Read from Peripherial
	 */
	dmaRX_->CCR	|= (0x01<<12 | MemPerphSize<<10 | MemPerphSize<<8 | 0x01<<7);
	dmaRX_->CPAR = reinterpret_cast<std::uint32_t>(&spiBase_->DR);							//SPI Data Register is Source Adress for DMA
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

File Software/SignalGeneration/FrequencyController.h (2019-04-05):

#ifndef FREQUENCYCONTROLLER_H
#define FREQUENCYCONTROLLER_H


#include <cstdint>
#include <cmath>
#include "SignalGenerationCommon.h"


namespace SignalGeneration {


template <typename TI2cSlaveDriver>
class FrequencyController
{
public:

	/* Constructor */
	explicit FrequencyController(const TI2cSlaveDriver& i2c);

	/* Destructor */
	~FrequencyController();

	/* Initialize Si5351 clock generator */
	auto initialize(void) const -> void;

	/* Get current output frequency */
	auto getCurrentFrequency(Output const channelNo) const -> std::uint32_t;

	/* Set Si5351 PLL and divider settings to output a appropriate input frequency for the
	 * synthesizer of given channel */
	auto setFrequencyForChannel(Output const channelNo, ChannelSettings const& settings) const  -> std::uint32_t;


private:

	/* Registers of the Si5351 */
	enum : std::uint8_t {
		SI5351_REGISTER_0_DEVICE_STATUS                       = 0,
		SI5351_REGISTER_1_INTERRUPT_STATUS_STICKY             = 1,
		SI5351_REGISTER_2_INTERRUPT_STATUS_MASK               = 2,
		SI5351_REGISTER_3_OUTPUT_ENABLE_CONTROL               = 3,
		SI5351_REGISTER_9_OEB_PIN_ENABLE_CONTROL              = 9,
		SI5351_REGISTER_15_PLL_INPUT_SOURCE                   = 15,
		SI5351_REGISTER_16_CLK0_CONTROL                       = 16,
		SI5351_REGISTER_17_CLK1_CONTROL                       = 17,
		SI5351_REGISTER_18_CLK2_CONTROL                       = 18,
		SI5351_REGISTER_19_CLK3_CONTROL                       = 19,
		SI5351_REGISTER_20_CLK4_CONTROL                       = 20,
		SI5351_REGISTER_21_CLK5_CONTROL                       = 21,
		SI5351_REGISTER_22_CLK6_CONTROL                       = 22,
		SI5351_REGISTER_23_CLK7_CONTROL                       = 23,
		SI5351_REGISTER_24_CLK3_0_DISABLE_STATE               = 24,
		SI5351_REGISTER_25_CLK7_4_DISABLE_STATE               = 25,
		SI5351_REGISTER_42_MULTISYNTH0_PARAMETERS_1           = 42,
		SI5351_REGISTER_43_MULTISYNTH0_PARAMETERS_2           = 43,
		SI5351_REGISTER_44_MULTISYNTH0_PARAMETERS_3           = 44,
		SI5351_REGISTER_45_MULTISYNTH0_PARAMETERS_4           = 45,
		SI5351_REGISTER_46_MULTISYNTH0_PARAMETERS_5           = 46,
		SI5351_REGISTER_47_MULTISYNTH0_PARAMETERS_6           = 47,
		SI5351_REGISTER_48_MULTISYNTH0_PARAMETERS_7           = 48,
		SI5351_REGISTER_49_MULTISYNTH0_PARAMETERS_8           = 49,
		SI5351_REGISTER_50_MULTISYNTH1_PARAMETERS_1           = 50,
		SI5351_REGISTER_51_MULTISYNTH1_PARAMETERS_2           = 51,
		SI5351_REGISTER_52_MULTISYNTH1_PARAMETERS_3           = 52,
		SI5351_REGISTER_53_MULTISYNTH1_PARAMETERS_4           = 53,
		SI5351_REGISTER_54_MULTISYNTH1_PARAMETERS_5           = 54,
		SI5351_REGISTER_55_MULTISYNTH1_PARAMETERS_6           = 55,
		SI5351_REGISTER_56_MULTISYNTH1_PARAMETERS_7           = 56,
		SI5351_REGISTER_57_MULTISYNTH1_PARAMETERS_8           = 57,
		SI5351_REGISTER_58_MULTISYNTH2_PARAMETERS_1           = 58,
		SI5351_REGISTER_59_MULTISYNTH2_PARAMETERS_2           = 59,
		SI5351_REGISTER_60_MULTISYNTH2_PARAMETERS_3           = 60,
		SI5351_REGISTER_61_MULTISYNTH2_PARAMETERS_4           = 61,
		SI5351_REGISTER_62_MULTISYNTH2_PARAMETERS_5           = 62,
		SI5351_REGISTER_63_MULTISYNTH2_PARAMETERS_6           = 63,
		SI5351_REGISTER_64_MULTISYNTH2_PARAMETERS_7           = 64,
		SI5351_REGISTER_65_MULTISYNTH2_PARAMETERS_8           = 65,
		SI5351_REGISTER_66_MULTISYNTH3_PARAMETERS_1           = 66,
		SI5351_REGISTER_67_MULTISYNTH3_PARAMETERS_2           = 67,
		SI5351_REGISTER_68_MULTISYNTH3_PARAMETERS_3           = 68,
		SI5351_REGISTER_69_MULTISYNTH3_PARAMETERS_4           = 69,
		SI5351_REGISTER_70_MULTISYNTH3_PARAMETERS_5           = 70,
		SI5351_REGISTER_71_MULTISYNTH3_PARAMETERS_6           = 71,
		SI5351_REGISTER_72_MULTISYNTH3_PARAMETERS_7           = 72,
		SI5351_REGISTER_73_MULTISYNTH3_PARAMETERS_8           = 73,
		SI5351_REGISTER_74_MULTISYNTH4_PARAMETERS_1           = 74,
		SI5351_REGISTER_75_MULTISYNTH4_PARAMETERS_2           = 75,
		SI5351_REGISTER_76_MULTISYNTH4_PARAMETERS_3           = 76,
		SI5351_REGISTER_77_MULTISYNTH4_PARAMETERS_4           = 77,
		SI5351_REGISTER_78_MULTISYNTH4_PARAMETERS_5           = 78,
		SI5351_REGISTER_79_MULTISYNTH4_PARAMETERS_6           = 79,
		SI5351_REGISTER_80_MULTISYNTH4_PARAMETERS_7           = 80,
		SI5351_REGISTER_81_MULTISYNTH4_PARAMETERS_8           = 81,
		SI5351_REGISTER_82_MULTISYNTH5_PARAMETERS_1           = 82,
		SI5351_REGISTER_83_MULTISYNTH5_PARAMETERS_2           = 83,
		SI5351_REGISTER_84_MULTISYNTH5_PARAMETERS_3           = 84,
		SI5351_REGISTER_85_MULTISYNTH5_PARAMETERS_4           = 85,
		SI5351_REGISTER_86_MULTISYNTH5_PARAMETERS_5           = 86,
		SI5351_REGISTER_87_MULTISYNTH5_PARAMETERS_6           = 87,
		SI5351_REGISTER_88_MULTISYNTH5_PARAMETERS_7           = 88,
		SI5351_REGISTER_89_MULTISYNTH5_PARAMETERS_8           = 89,
		SI5351_REGISTER_90_MULTISYNTH6_PARAMETERS             = 90,
		SI5351_REGISTER_91_MULTISYNTH7_PARAMETERS             = 91,
		SI5351_REGISTER_092_CLOCK_6_7_OUTPUT_DIVIDER          = 92,
		SI5351_REGISTER_165_CLK0_INITIAL_PHASE_OFFSET         = 165,
		SI5351_REGISTER_166_CLK1_INITIAL_PHASE_OFFSET         = 166,
		SI5351_REGISTER_167_CLK2_INITIAL_PHASE_OFFSET         = 167,
		SI5351_REGISTER_168_CLK3_INITIAL_PHASE_OFFSET         = 168,
		SI5351_REGISTER_169_CLK4_INITIAL_PHASE_OFFSET         = 169,
		SI5351_REGISTER_170_CLK5_INITIAL_PHASE_OFFSET         = 170,
		SI5351_REGISTER_177_PLL_RESET                         = 177,
		SI5351_REGISTER_183_CRYSTAL_INTERNAL_LOAD_CAPACITANCE = 183
	};

	enum Si5351PLL_t : std::uint8_t {
		SI5351_PLL_A = 0,
		SI5351_PLL_B
	};

	enum Si5351RDiv_t : std::uint8_t {
		SI5351_R_DIV_1   = 0,
		SI5351_R_DIV_2   = 1,
		SI5351_R_DIV_4   = 2,
		SI5351_R_DIV_8   = 3,
		SI5351_R_DIV_16  = 4,
		SI5351_R_DIV_32  = 5,
		SI5351_R_DIV_64  = 6,
		SI5351_R_DIV_128 = 7
	};

	enum Si5351CrystalLoad_t : std::uint16_t {
	  SI5351_CRYSTAL_LOAD_6PF  = (1<<6),
	  SI5351_CRYSTAL_LOAD_8PF  = (2<<6),
	  SI5351_CRYSTAL_LOAD_10PF = (3<<6)
	} ;

	enum Si5351CrystalFreq_t : std::uint32_t {
	  SI5351_CRYSTAL_FREQ_25MHZ = (25000000),
	  SI5351_CRYSTAL_FREQ_27MHZ = (27000000)
	};

	/* Methods to configure PLLs and multisynth dividers of the Si5351 */
	auto setPLL(Si5351PLL_t const pll, std::uint32_t const mult, std::uint32_t const num,
			std::uint32_t const denom) const -> void;

	auto setDivider(std::uint8_t const output, Si5351PLL_t const pll, std::uint32_t const msDiv,
			std::uint32_t const msNum, std::uint32_t const msDenom, Si5351RDiv_t const rDiv) const -> void;

	/* Array for the divider for each channel */
	mutable std::array<std::uint32_t, Output::NumOfOutputs> channelFrequencies_;

	const TI2cSlaveDriver& i2c_;
};


template <typename TI2cSlaveDriver>
FrequencyController<TI2cSlaveDriver>::
FrequencyController(const TI2cSlaveDriver& i2c) :
	i2c_(i2c)
{
}


template <typename TI2cSlaveDriver>
FrequencyController<TI2cSlaveDriver>::
~FrequencyController()
{
}
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

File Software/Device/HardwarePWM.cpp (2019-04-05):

#include <HardwarePWM.h>
#include <cstdint>
#include <functional>
#include "stm32l476xx.h"

//---------------------------------------------------------------------------------------
//--------------------- Implementation of Class 'HardwarePWM' ---------------------------

Device::HardwarePWM::
HardwarePWM(TIM_TypeDef* const timer_base, GPIO_TypeDef* const gpio_base, const uint8_t gpio_pin) :
	timerBase_(timer_base),
	channel_(0)
{
	/* Pulse Width Modulation for Display Background Light
	 *
	 *	PWM1 green	PC8 TIM3 CH3
	 *	alternative		TIM8 CH3
	 *
	 *
	 *	PWM2 red 	PC9 TIM8 CH4
	 *	alternative		TIM3 CH4
	 *
	 */

	/* Enable clock for GPIO port */
	std::uint8_t bitPos = (reinterpret_cast<std::uint32_t>(gpio_base) - AHB2PERIPH_BASE)>>10;
	RCC->AHB2ENR		|= 0x01<<bitPos;

	/* Enable clock for Timer */
	if(timerBase_ == TIM8)
	{
		RCC->APB2ENR		|= 0x01<<13;	//Enable Timer 8
	}
	else
	{
		bitPos = (reinterpret_cast<std::uint32_t>(timer_base) - APB1PERIPH_BASE)>>10;
		RCC->APB1ENR1		|= 0x01<<bitPos;
	}

	/* Configure GPIO pin */
	gpio_base->MODER	 = (gpio_base->MODER & ~(0x03<<(2*gpio_pin))) | (0x02<<(2*gpio_pin));	/* Alternate function mode */
	gpio_base->OTYPER 	&= ~(0x01<<gpio_pin);		/* Output push pull */
	gpio_base->OSPEEDR	|= 0x03<<(2*gpio_pin);		/* Very high speed */
	gpio_base->PUPDR	&= ~(0x03<<(2*gpio_pin));	/* No pull-up / pull-down */

	/* Set alternate function */
	std::uint8_t alternateFunction = (timer_base == TIM8) ? 3 : 2; // 2 for TIM1, TIM2, TIM4, TIM5; 3 for TIM8
	if (gpio_pin <= 7) {
		gpio_base->AFR[0] = (gpio_base->AFR[0] & ~(0x0F<<(gpio_pin*4))) | alternateFunction<<(gpio_pin*4);
	}
	else {
		gpio_base->AFR[1] = (gpio_base->AFR[1] & ~(0x0F<<((gpio_pin-8)*4))) | alternateFunction<<((gpio_pin-8)*4);
	}


	/* Configure Timer */
	timerBase_->CR1		&= ~(0x01<<0);

	timerBase_->CR1 	|= (0x01<<7); // | 0x01<<4); // | 0x01<<2);
	//timerBase_->DIER 	&= ~(0x01<<0);
	if(timerBase_ == TIM8)
	{
		timerBase_->BDTR	|= 0x01<<14;	//Automatic Output enable
	}

	/* Check which channel to use */
	if (gpio_base == GPIOA) {
		if (gpio_pin <= 3) {
			channel_ = gpio_pin + 1;
		}
		else if ((gpio_pin == 6) || (gpio_pin == 7)) {
			channel_ = gpio_pin - 5;
		}
	}
	else if (gpio_base == GPIOB) {
		if ((gpio_pin == 4) || (gpio_pin == 6)) {
			channel_ = 1;
		}
		else if ((gpio_pin == 5) || (gpio_pin == 7)) {
			channel_ = 2;
		}
		else if ((gpio_pin == 0) || (gpio_pin == 8)) {
			channel_ = 3;
		}
		else if ((gpio_pin == 1) || (gpio_pin == 9)) {
			channel_ = 4;
		}
	}
	else if (gpio_base == GPIOC) {
		if ((gpio_pin >= 6) && (gpio_pin <= 9)) {
			channel_ = gpio_pin - 5;
		}
	}
	else if (gpio_base == GPIOD) {
		if (gpio_pin >= 12) {
			channel_ = gpio_pin - 11;
		}
	}
	else if (gpio_base == GPIOE) {
		if ((gpio_pin >= 3) && (gpio_pin <= 6)) {
			channel_ = gpio_pin - 2;
		}
	}
	else if (gpio_base == GPIOF) {
		if ((gpio_pin >= 6) && (gpio_pin <= 9)) {
			channel_ = gpio_pin - 5;
		}
	}

	/* Configure channel settings */
	if ((channel_ == 1) || (channel_ == 2)) {
		timerBase_->CCMR1	= (timerBase_->CCMR1 & ~(0xFF<<((channel_-1)*8))) | (0x01<<(((channel_-1)*8)+3) | 0x06<<(((channel_-1)*8)+4));
	}
	else if ((channel_ == 3) || (channel_ == 4)) {
		timerBase_->CCMR2   = (timerBase_->CCMR2 & ~(0xFF<<((channel_-3)*8))) | (0x01<<(((channel_-3)*8)+3) | 0x06<<(((channel_-3)*8)+4));
	}

	/* Set max timer value */
	timerBase_->ARR	 = 0xFFFF;

	/* Set duty cycle to 50% (default) */
	setDutyCycle(50);
}

Device::HardwarePWM::
~HardwarePWM(void)
{

}


void Device::HardwarePWM::
enable(void) const
{
	/* Disable timer */
	timerBase_->CR1		&= ~(0x01<<0);

	/* Enable output */
	timerBase_->CCER	|= (0x01<<((channel_-1)*4));

	/* Create an update event to use the new settings */
	timerBase_->EGR		|= 0x01<<0;

	/* Enable timer */
	timerBase_->CR1		|= 0x01<<0;
}


void Device::HardwarePWM::
disable(void) const
{
	/* Disable timer */
	timerBase_->CR1		&= ~(0x01<<0);

	/* Disable output */
	timerBase_->CCER	&= ~(0x01<<((channel_-1)*4));

	/* Create an update event to use the new settings */
	timerBase_->EGR		|= 0x01<<0;

	/* Enable timer */
	timerBase_->CR1		|= 0x01<<0;
}


void Device::HardwarePWM::
setDutyCycle(const std::uint8_t percent) const
{
	/* Disable timer */
	timerBase_->CR1		&= ~(0x01<<0);

	/* Update settings for new duty cycle */
	if (channel_ == 1) {
		timerBase_->CCR1 = ((0xFFFF * percent) / 100);
	}
	else if (channel_ == 2) {
		timerBase_->CCR2 = ((0xFFFF * percent) / 100);
	}
	else if (channel_ == 3) {
		timerBase_->CCR3 = ((0xFFFF * percent) / 100);
	}
	else if (channel_ == 4) {
		timerBase_->CCR4 = ((0xFFFF * percent) / 100);
	}

	/* Create an update event to use the new settings */
	timerBase_->EGR		|= 0x01<<0;

	/* Enable timer */
	timerBase_->CR1		|= 0x01<<0;
}

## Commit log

2019-04-05 Added Hardware documents
    [Frontpanel.brd, Frontpanel.sch, Hauptplatine.brd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]
2019-04-05 Added microcontroller firmware in Software folder
    [waveformgenerator2 Debug.cfg, waveformgenerator2 Release.cfg]
2019-04-09 Added two images of the complete and finished device

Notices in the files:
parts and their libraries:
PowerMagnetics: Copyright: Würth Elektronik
